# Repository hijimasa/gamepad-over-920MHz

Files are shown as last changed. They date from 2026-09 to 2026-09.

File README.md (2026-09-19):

# gamepad-over-920MHz

**USB ゲームパッドを 920MHz 帯（IM920sL）で無線化する**ファームウェアです。
Bluetooth より遠くまで届く無線リンクに載せ替えつつ、PC からは**普通のゲームパッドのまま**に見せます。
ロボットの遠隔操縦を想定しています。

```
[USBゲームパッド] ─USB(PIO-USB)→ [送信機 XIAO RP2040] ─UART→ [IM920sL]
                                                                 │ 920MHz
[PC] ←USB HID + CDC─ [受信機 XIAO RP2040] ←UART─ [IM920sL] ←─────┘
```

## 特徴

- **軸番号・ボタン番号が元のパッドと一致する。** 送信機がパッドの HID レポート
  ディスクリプタを解析して軸構成を無線で送り、受信機がそれに合わせて HID
  ディスクリプタを実行時に組み立てます。**受信機側の設定は不要**で、
  `/dev/input/js0` の番号が直挿しと同じになるので、既存のソフトをそのまま使えます。
- **フェイルセーフ。** 有効なパケットが 300ms 途絶えると、受信機は全軸中立・
  全ボタン OFF を出力します（実測で約 300ms、ログにも残ります）。
- **リンクの生死が送信機側でも分かる。** 受信機から 2 秒ごとにハートビートを返し、
  「受信機が前方向を受信できているか」まで含めて LED に反映します。
- **チャンネル自動選定。** 起動時に 31〜45 の雑音を測って空いているチャンネルへ移動します。
  複数ペアを同時に運用しても電波を取り合いません。通信が途絶えたら待ち合わせ用の
  ch31 へ自動で戻ります。
- **暗号化（AES-GCM 256bit）。** 同じグループ番号さえ合えば誰でも操作できてしまう
  状態を防げます。
- **USB CDC コンソール。** 設定・ペアリング・電波品質の確認・配線の切り分けができます。

Linux と Windows の両方で動作を確認しています（macOS は未確認ですが、標準の HID と
CDC しか使っていないため動く見込みです）。

## 必要なもの

| | 品目 | 備考 |
|---|---|---|
| 送信機 | Seeed XIAO RP2040 ×1 | CPU 240MHz で動かす（PIO-USB の要件） |
| 送信機 | IM920sL ＋ IM920sL-ADP ×1 | 変換アダプタ経由で 2.54mm に |
| 送信機 | USB Type-A メスコネクタ | ゲームパッド接続用 |
| 送信機 | モバイルバッテリー | 実測の消費電流は約 60mA |
| 受信機 | Seeed XIAO RP2040 ×1 | PC に USB-C で接続 |
| 受信機 | IM920sL ＋ IM920sL-ADP ×1 | |

配線は [docs/schematic/gamepad_wireless_schematic.svg](docs/schematic/gamepad_wireless_schematic.svg)（Rev.3）、
部品表は [docs/gamepad_wireless_BOM.xlsx](docs/gamepad_wireless_BOM.xlsx) を参照してください。

基板（送信機・受信機で共通、100×62mm 2層）の KiCad データと発注用ガーバーは
[hardware/](hardware/) にあります。ブレッドボードやユニバーサル基板で組む場合は
[docs/netlist.md](docs/netlist.md) にネットリストとレイアウト制約があります。

> IM920sL 本体と変換アダプタの取扱説明書は、メーカー（インタープラン）の配布物なので
> リポジトリには含めていません。<https://www.interplan.co.jp/> から入手し、
> `docs/IM920sL_manual.pdf` / `docs/IM920sL_ADP_manual.pdf` として置くと、
> 本 README 中の参照（コマンド仕様・端子表・チャンネル表）と対応します。

## 最短の始め方

```bash
# 1. ビルド環境（arduino-cli）
arduino-cli config add board_manager.additional_urls \
  https://github.com/earlephilhower/arduino-pico/releases/download/global/package_rp2040_index.json
arduino-cli core update-index
arduino-cli core install rp2040:rp2040
arduino-cli lib install "Pico PIO USB" "Adafruit NeoPixel"

# 2. 書込み
./build.sh rx upload /dev/ttyACM0   # 受信機
./build.sh tx upload /dev/ttyACM1   # 送信機

# 3. ペアリング（初回だけ。両機を 50cm 以内に置く）
#    起動後 5 秒以内（LED が水色の速い点滅）か、赤点滅中に
#    受信機 → 送信機 の順に BOOTSEL を 3 秒以上長押し

# 4. 確認
tools/jsinfo.py 10     # /dev/input/js0 の軸数・ボタン数とライブの値
```

うまくいくと**両機とも緑点灯**になり、PC に `irlab Wireless Gamepad` として
ゲームパッドが現れます。

詳しい操作は[操作（BOOTSEL ボタン ／ CDC コンソール）](#操作bootsel-ボタン--cdc-コンソール)、
うまくいかないときは[診断に使えるコマンド](#診断に使えるコマンド)を参照してください。

## 免責

**個人が趣味・研究用に作った原理試作です。**動作・性能・安全性のいずれも保証しません。

- 無線の到達距離や通信の安定性は、設置場所の電波環境に大きく左右されます。
  同じ構成でも結果は異なります。
- ロボットなど**物理的に動くものを制御する用途では、本装置とは独立した非常停止手段を
  必ず用意してください。**受信側に 300ms のフェイルセーフを実装してありますが、
  これは「通信が途絶えたら中立を出力する」だけのもので、機器の安全を保証するものでは
  ありません。
- 本リポジトリの成果物（ファームウェア、回路図、基板データ、資料）を使用した結果
  生じたいかなる損害についても、作者は責任を負いません。
- 920MHz 帯の利用は国と地域の法令に従ってください。IM920sL は日本国内の電波法認証を
  取得済みの製品ですが、**モジュールを改造したり国外で使用したりする場合は、
  使用者の責任において適法性を確認してください。**

不具合や改善点を見つけたら Issue や Pull Request で教えていただけると助かります。

## ライセンス

MIT License（[LICENSE](LICENSE)）。無保証です（上記「免責」および LICENSE の
"AS IS" 条項を参照）。

---

以下は実装と実機検証の詳細です。立ち上げで踏んだ問題（PIO-USB の 240MHz 要件、
TxD/RxD 逆接続の切り分け、コア1 だけが死ぬ故障モードなど）も記録してあります。

## ビルドと書込み

```bash
./build.sh tx                       # 送信機をビルド
./build.sh rx                       # 受信機をビルド
./build.sh tx upload /dev/ttyACM0   # ビルドして書込み
```

必要な環境:

- arduino-cli ＋ `rp2040:rp2040`（earlephilhower コア）
- ライブラリ `Pico PIO USB`、`Adafruit NeoPixel`
- FQBN
  - TX: `rp2040:rp2040:seeed_xiao_rp2040:usbstack=tinyusb,freq=240`
    （PIO-USB は 12MHz の倍数が必要。**120MHz ではタイミング余裕が足りず列挙に失敗した**ので 240MHz。
    `WG_FREQ=120 ./build.sh tx` で変更可）
  - RX: `rp2040:rp2040:seeed_xiao_rp2040:usbstack=tinyusb`

書込みは 1200bps タッチで自動的にブートローダへ入る。入らないときは BOOTSEL を押しながら
USB を挿し、`RPI-RP2` に `build/<role>/*.uf2` をコピーする。

## 構成

```
firmware/common/     TX・RX 共通（arduino-cli には --library で渡す）
  packet.h           無線パケット（State 12 バイト / Info 10 バイト）
  im920sl_config.h   IM920sL の設定・送受信（元からあったもの＋追記）
  im920_diag.h       配線切り分け用の diag / raw / scan
  hid_gamepad_map.h  パッドの HID ディスクリプタを解析して状態を取り出す（TX）
  hid_desc_builder.h HID ディスクリプタを実行時に組み立てる（RX）
  status_led.h       オンボード LED の状態表示
firmware/tx/tx.ino   送信機
firmware/rx/rx.ino   受信機
tools/console.py     CDC コンソールにコマンドを送る補助ツール
```

## 状態表示 LED

XIAO RP2040 のオンボード NeoPixel（GPIO12／電源 GPIO11）と三色 LED（R17/G16/B25）を同時に駆動する。

| 色 | 状態 |
|---|---|
| 赤の点滅 | 接続なし（TX: パッド未接続か送信が通らない／RX: フェイルセーフ中） |
| 黄の点滅 | ペアリング中 |
| 緑の点灯 | 接続中（送信機は**受信機からの応答が届いている**ときだけ） |
| 青の点灯 | 設定ブリッジ中 |
| 白の点滅 | 起動処理中 |
| **水色の速い点滅** | **BOOTSEL ボタン受付中（起動直後 5 秒）** |
| 赤紫の速い点滅 | IM920sL の設定に失敗 |

## 操作（BOOTSEL ボタン ／ CDC コンソール）

SW1 は未実装なので **BOOTSEL ボタン**を使う。電源投入時に押したままだと書込みモードに
入ってしまうため、**電源を入れてから押す**必要がある。押せるタイミングは 2 つ:

**1. 起動直後の受付ウィンドウ（LED が水色の速い点滅、5 秒間）**

電源を入れると 白点滅（起動処理）→ **水色の速い点滅（受付中）** と変わる。
水色の間に押す。

**2. 運用中、リンクが確立していないとき（LED が赤点滅）**

組み立て直後でまだペアリングしていない状態は赤点滅になるので、**そのまま押せばよい**。
緑点灯（正常動作中）のときはボタンを一切読まないので、運用中の通信を乱すことはない。

- 短押し（3 秒未満）→ 設定ブリッジ
- **3 秒以上の長押し → ペアリング**（TX＝子機、RX＝親機。両機を 50cm 以内に置く）

押している間は LED が黄点滅になるので、3 秒の長押しはそれを見ながら数えられる。

> BOOTSEL の読み取りは XIP（フラッシュ実行）を一瞬止めてもう一方のコアを idle にするため、
> PIO-USB が動作中は避けたい。そのため送信機では、パッドが列挙済みになるか起動から
> 15 秒経つまでは運用中のポーリングを行わない。

### 組み立て後の初回手順

1. 受信機を PC に、送信機にゲームパッドとモバイルバッテリーを繋ぐ
2. 両方とも赤点滅になる（＝まだペアリングしていない）
3. 両機を 50cm 以内に置く
4. **受信機の BOOTSEL を 3 秒以上長押し**（親機として登録パケットを送る）
5. すぐに**送信機の BOOTSEL も 3 秒以上長押し**（子機として受け取る）
6. 成功すると両方とも緑点灯になる

ペアリングは Flash に保存されるので**初回だけ**でよい（[ペアリングは初回だけ](#ペアリングは初回だけ) 参照）。

USB-C の CDC コンソール（`tools/console.py` か `screen /dev/ttyACM0 115200`）:

| コマンド | 内容 |
|---|---|
| `help` | コマンド一覧 |
| `status` | IM920sL の設定値、受信状況（RSSI・seq 欠番）、パッドの状態 |
| `config` | AutoConfig（目標値と違う項目だけ ENWR で書込み） |
| `pair` | ペアリング |
| `bridge` | USB CDC ↔ IM920sL の透過ブリッジ |
| `dump` | （TX）HID 生レポートの表示 |
| `map` | （TX）解析した HID マップ |
| `profile` / `reset` | （RX）HID 構成の表示／既定値に戻して再起動 |
| `diag` / `raw <cmd>` / `scan` | IM920sL の配線・応答の切り分け |

## ペアリングは初回だけ

グループ番号は `ENWR` でモジュールの Flash に書かれる不揮発設定なので、電源を切っても残る。
実測（両機を再起動して確認）:

```
再起動前: TX RDGN=0001D9D8 / RX RDGN=0001D9D8
再起動後: TX RDGN=0001D9D8 / RX RDGN=0001D9D8   ← 保持
link: UP  RSSI=-19dBm  packets=116 bad=0        ← 自動で復帰
```

ペアリングが要るのは **初回**と、**どちらかのモジュールを交換したとき**
（グループ番号は親機の固有 ID から決まる）、あるいは `RDGN` が `FFFFFFFF` に
戻ってしまったときだけ。**ファームを書き直しても不要**（`im920AutoConfig()` は
STNN/STRT/STCH/STPO/STTR しか触らない）。

⚠ Flash の書換えは全項目合計で 10 万回まで。ペアリングを不必要に繰り返さないこと。
`im920AutoConfig()` も「目標値と違う項目だけ」書くので、設定が合っていれば書き込まない。

## 軸番号・ボタン番号を元のパッドに合わせる仕組み

既存の操縦ソフトが `/dev/input/js0` を直接読んでいる場合、軸とボタンの並びが
元のパッドと一致していないと、受信機に差し替えた途端に割り当てがずれる。
joydev は **ABS\_\* コードの昇順**に軸番号を振る
（X=0, Y=1, Z=2, Rx=3, Ry=4, Rz=5, Hat=6,7）ので、**元のパッドに在る軸の集合**が
一致していれば番号も一致する。そのため、

1. TX は VID:PID の決め打ち表ではなく、**HID レポートディスクリプタを解析**して
   Usage（X, Y, Z, Rx, Ry, Rz, Hat switch, Button 1..n）の位置を求める。
   → どのパッドでも Linux の hid-generic と同じ割り当てになる。
2. TX は軸の種類（axisMask）とボタン数を **Info パケット**で 2 秒ごとに送る。
3. RX は受け取った構成を EEPROM に保存し、**HID ディスクリプタを実行時に組み立てる**。
   構成が変わったときは保存して自動で再起動し、新しいディスクリプタで列挙し直す。

つまり **受信機側の設定は不要**。送信機にパッドを繋げば、受信機が自動的に同じ形の
ゲームパッドとして PC に見えるようになる（初回は 1 回だけ自動再起動する）。

`dump` で生レポート、`map` で解析結果、RX の `profile` で現在の構成を確認できる。

## Linux 以外の OS で使えるか

受信機は標準的な **USB HID ゲームパッド＋CDC の複合デバイス**なので、Windows / macOS でも
追加ドライバなしで動く。実際のディスクリプタ:

```
bDeviceClass 239 / bDeviceSubClass 2 / bDeviceProtocol 1   ← IAD 複合デバイス宣言
  インタフェース 0,1: CDC（Communications + CDC Data）
  インタフェース 2  : HID（Usage Page = Generic Desktop, Usage = Game Pad）
```

- **HID**: Windows 標準の HID ドライバで動く。`joy.cpl`・DirectInput・RawInput から見える。macOS も標準対応
- **CDC**: Windows 10/11 は `usbser.inf` 内蔵で COM ポートとして見える。macOS は `/dev/cu.usbmodem*`
- **IAD 宣言**がないと Windows が複合デバイスを正しく分解できないが、TinyUSB が付けている

### 注意点

- **XInput ではない**。Windows で XInput 専用のゲームからは見えない。
  これは F310 を D モードで使うのと同じ制約。
  DirectInput / RawInput 対応のソフトなら問題ない。
- 軸・ボタン番号は、Linux の joydev が ABS コード順、Windows の DirectInput が
  HID Usage 順で決まるので、同じ Usage を出している限り一致するはず。**Windows 実機は未確認**。
- VID:PID は Adafruit の既定値 `239a:cafe` のまま。機能上は問題ないが、
  外部に配布するなら自前の PID を用意するのが望ましい。

### Windows 向けに入れてある対策

1. **シリアル番号の衝突回避** — 手元の 2 枚は同じチップ ID（`4250305539333104`）を返す。
   Windows は VID/PID/シリアルでインスタンスを識別するため、同じ PC に両方挿すと衝突しうる。
   役割の接頭辞を付けている（`WGTX-...` / `WGRX-...`）。
2. **HID ディスクリプタのキャッシュ対策** — Windows はレポートディスクリプタを
   VID/PID/**REV** 単位でキャッシュする。受信機はプロファイル学習でディスクリプタを
   作り直すので、構成から `bcdDevice` を生成して別リビジョンとして見せている
   （例: axisMask 0x27・ボタン 12・ハットあり → `bcdDevice = 27.19`）。

## 取扱説明書との照合（docs/IM920sL_manual.pdf Rev.1.5）

公式資料と全コマンド・全設定値を突き合わせ済み。**仕様違反は無かった。**

- **ch31＋高速モード（STRT 1）は仕様上有効**。`STCH` は「01〜29、31〜45」とだけ規定され、
  通信モードによる制限は無い（モードが決めるのは既定値のみ）。
  4s モード（31〜45）は「1 時間あたりの送信時間の総和 **制限なし**」と明記。
  電波法上の処理はモジュール内部で自動なので、ファーム側で duty を管理する義務は無い。
- 発行している 14 コマンドの名称・引数書式・応答・前提条件・順序依存はすべて資料どおり
  （`STNN 0001` に ENWR 必須、`STRT`→`STCH` の順、ペアリング後は RESET 端子必須）。
- 受信行 `aa,bbbb,dd:`、**RSSI は符号付き**（`9Ch`=−100dBm）、TXDA は 1〜32 バイト、
  送信時間 `4.56ms + 80µs × バイト数`（12 バイトで 5.52ms）— すべて一致。
- 触っている設定は次の 5 つだけ（それ以外は初期値のまま）。

  | コマンド | 内容 | 設定値 |
  |---|---|---|
  | `STNN` | ノード番号 | 受信機（親機）= **0001**、送信機 = **0002** |
  | `STRT` | 通信モード | **1**（高速 100kbps） |
  | `STCH` | チャネル | **31**（起動後に空きチャネルへ移動） |
  | `STPO` | 送信出力 | **2**（10mW） |
  | `STTR` | キャリアセンス NG 時の自動リトライ | **00**（再送はファーム側で判断する） |

- **ADP の J1/J2 対応**も回路図で確認。`J1-n = 本体 pin(2n−1)`、`J2-n = pin(2n)`。
  本体 pin1 は資料により `IO1/BUSY`、ADP 回路図では `IO1/RTS` と表記が違うが同じ端子。

### ユニキャストと ACK について

`TXDU`（ユニキャスト）は実在し「**OK は相手に届いたことを示す**」と明記されている。
ただし**ルート探索を行い、失敗時は自動で最大 10 回リトライ**するため遅延が大きくばらつく
（資料も「リアルタイム性が要求される用途では十分ご注意ください」と注意喚起）。
30ms 周期の操縦データには不向きなので採用していない。

各パケットは差分ではなく**現在の全状態**を持つので、落ちても次のパケットが完全に
上書きする。再送は「古い状態を届けたうえに新しい状態を遅らせる」ため逆効果。
取りこぼしへの対処は受信側の 300ms フェイルセーフで行う。

なお `TXSB`（センドバック送信）はルート探索なしで送信元へ返せるので、
ハートビートをブロードキャストからユニキャストに変えたい場合の選択肢になる（未採用）。

### 4s モードの送信休止規定（2026-09-19 に再確認）

取扱説明書 表1・§7-3 より、ch31〜45（4s モード）の規定は次のとおり。

| 項目 | 4s モード（ch31〜45） | 360s モード（ch01〜29） |
|---|---|---|
| キャリアセンス時間 | 約 6ms | 128µs〜1ms |
| 送信休止時間 | **52ms 以上** | 2ms 以上 |
| 1 時間あたりの送信時間の総和 | **なし** | 360 秒以内 |
| 送信時間制限 | 3.9 秒以下 | 400ms 以下 |

「1 時間 360 秒」の総和制限は ch01〜29 だけの話で、本プロジェクトの ch31〜45 には無い。

代わりに効くのが**送信休止 52ms** で、挙動は「最初の送信から 3.9 秒を超えたら 52ms 休止」
「4 秒経過前に 52ms 以上空けば窓がリセットされる」。
1 回の占有はキャリアセンス約 6ms ＋ 送信 6ms（12 バイト時 5.52ms を切り上げ）＝ 約 12ms
なので、計算上は **64ms 間隔**あれば窓がリセットされ続けるはず。

**ただし実測はこの計算と合わない。** ブリッジ経由でファームを介さず TXDA を打った結果:

| 送信間隔 | 55ms | 65ms | 75ms | 90ms | 120ms | 150ms |
|---|---|---|---|---|---|---|
| NG 率 | 20.0% | 17.5% | 12.5% | 8.0% | 4.0% | **0%** |

64ms を超えても NG は残り、0 になるのは 150ms 以上。**機構は特定できていない。**

なお **NG は一度も連続しなかった**（90ms で 12 回、120ms で 6 回、すべて単発）。
欠落は最悪 2 周期分なので、受信側フェイルセーフ 300ms には届かない。

⚠ 暗号化を有効にすると 1 パケットが **24 バイト増える**（§7-4）ので、
12 バイトのパケットは 36 バイト相当（7.44ms）になる。上の測定は暗号化なしの値。

## UART の高速化（115200bps）

12 バイト送信の UART 時間は 19200bps で約 16ms あり、**電波の送信時間 5.5ms の 3 倍**を
食っていた。`SBRT 7` で 115200bps にすると約 2.7ms になる。

`SBRT` は資料に「Flash メモリに記憶します」の記載が無く揮発性とみられるため、
**毎起動で設定しても Flash 書換え回数を消費しない**。起動時に `im920SetupBaud()` が
`RDVR` の応答でモジュールの現在のボーレートを判別し、必要なら 115200 に上げる。
判別に失敗したときは元のボーレートのまま動作を続ける。

## パケット暗号化＋送信元認証

AES-GCM 256bit。**同じグループ番号さえ合えば誰でもロボットを操作できる**状態を防ぐ。

```
enc <16進64桁>   キーを設定して有効化（両機に同じキーを入れること）
enc off          無効化（キーは残る）
```

- `STKY` は ENWR 中のみ実行可能で Flash に記憶される（読出しコマンドは無い）ため、
  明示的なコマンドのときだけ設定する
- 通信時間が 24 バイト分（高速モードで約 1.9ms）増える
- ペアリング（STGN）時は常に非暗号化パケットなので、順序はどちらでもよい
- 実測: 暗号化オンで `ng=0%`、`bad=0`、`lostEvents=0`

## 無線パケット

**State（12 バイト。30〜100ms ごと）**

| オフセット | 内容 |
|---|---|
| 0 | seq |
| 1–2 | buttons（u16 LE、bit0 = ボタン 1） |
| 3 | hat（0〜7 が方向（0=上、時計回り）、8 = 中立） |
| 4–9 | 軸 6 個 = **X, Y, Z, Rx, Ry, Rz**（0x80 が中立。スティック/トリガではなく **HID Usage 順**で並べている。理由は「軸番号・ボタン番号を元のパッドに合わせる仕組み」を参照） |
| 10 | flags（bit0: パッド接続中） |
| 11 | checksum（byte0〜10 の XOR） |

**Heartbeat（4 バイト。受信機 → 送信機、2 秒ごと）**
`0xC3`, seq, 受信機側の RSSI(i8), XOR。

`TXDA` はブロードキャストで ACK がないため、送信機は自分の電波が届いたかを知る手段がない。
そのままだと送信機の緑は「モジュールが送信を受理した」ことしか意味せず、
**受信機の電源が落ちていても緑**になってしまう。そこで受信機から定期的に投げ返し、
送信機はこれが 1.5 秒途切れたら赤点滅にする。受信機側の RSSI も載せているので、
送信機のコンソールで**両方向の電波強度**が見える（距離試験に便利）。

⚠ **周期を短くすると前方向のパケットが落ちる。** 半二重なので、受信機が
ハートビートを送っている間はパッドのパケットを受け取れない。実測:

| ハートビート周期 | 受信パケット | seqDrop | 300ms 途絶の回数 |
|---|---|---|---|
| 500ms | 11502 | 901（7.8%） | 870 |
| 2000ms | 203 | 0（0%） | 0 |

送信機の NG 率（キャリアセンス）は 2Hz でも +1% 程度しか増えないので、
一見すると安く見えるが、**効いてくるのは受信側の取りこぼし**のほう。
既定は 2 秒、送信機のリンク判定タイムアウトは 5 秒。
受信機は応答を待たずに投げる（`im920SendNoWait`）ので HID の処理は止まらない。

**Info（10 バイト。2 秒ごと）** `0xA5`, version, axisMask, buttonCount, caps(bit0=hat), VID, PID, XOR。
長さでどちらのパケットか判別する。

送信は「状態が変わったら即送信＋無変化でも 100ms ごと」「最短間隔 30ms」。`TXDA` が NG でも
再送はせず次の周期に任せる。

## 動作中に突然リンク断になる問題（2026-09-19 修正）

送信機のモジュールは**半二重**で、自分が送信している間は受信できない。
そのため送信間隔によって、受信機からのハートビートの取りこぼし率が大きく変わる。

| 送信間隔 | ハートビート欠落 |
|---|---|
| 60ms（パッド静止） | 6.6% |
| **30ms（操作中）** | **29.5%** |

ハートビートは 2 秒周期なので、旧設定の `HB_TIMEOUT_MS = 5000` では
**2 回連続で落ちるだけ**（操作中は 8.7%／2 秒ごと）でリンク断と誤判定していた。
平均 20〜30 秒に 1 回、動作中に突然赤点滅する原因。

さらに `CH_REVERT_MS = 12000` も同じハートビート頼りで、6 回連続の欠落で
ch31 に戻って再走査に入る。受信機が取り残されるので**本当の通信断**になっていた。

| 定数 | 変更前 | 変更後 | 必要な連続欠落 |
|---|---|---|---|
| `HB_TIMEOUT_MS` | 5000 | **15000** | 2 回 → 7 回 |
| `CH_REVERT_MS` | 12000 | **30000** | 6 回 → 15 回 |

ロボットの保護は受信側の 300ms フェイルセーフが行うので、送信側のリンク判定を
鈍くしても安全性は落ちない（送信機の LED は状態表示にすぎない）。

修正後、操作中相当（30ms 連続送信）で 225 秒間、`link: DOWN`・再走査とも 0 回。
またハートビートの欠落自体も 29.5% → 約 7% に下がった。誤判定による再走査が
さらにハートビートを失わせる悪循環になっていたとみられる。

**半二重による取りこぼし自体は解消していない。** しきい値を実測に合わせた修正である。

## `pad: reports` が増えないのは異常ではない

送信機の `status` が出す `reports` は、**パッドから HID レポートが届いた回数**。
多くのゲームパッド（Logitech F310 など）は状態が変化したときだけレポートを返すので、
**パッドを触っていなければ `reports=1` のまま**になる。これは正常。

実際に操作すると増える（実測で 2512 まで上がることを確認済み）。
PIO-USB が死んでいるかどうかは `usb` コマンドの
`epErr` / `epStall` / `コア1: loop1 通算` で判断すること。

## 動作中の突然の再起動＝core1（PIO-USB）の停止

送信機に**再起動しても消えないブラックボックス記録**（`__uninitialized_ram`）を入れて
現行犯で捕らえた結果、原因が確定した。

```
ブラックボックス: ソフト再起動 1 回 / 赤点滅 1 回
  赤点滅の内訳: パッド切断=1 USBホスト停止=0 ハートビート途絶=0 受信機側=0
  直近の自動再起動: コア1(PIO-USB)の停止
                    （稼働 265717ms, reports=1 ok=2764 ng=309, ハートビート 223ms 前）
```

- **無線は無関係。** 停止時点でハートビートは 223ms 前に届いており、リンクは健全だった
- 赤点滅の原因は**パッド切断**で、その 9 秒後に監視機構が再起動をかけている
- `loop1()` は `g_hostTicks++` が先頭なので、止まっているのは **`USBHost.task()` の中**

受信機側のログで実際の通信断も測れた:

```
途絶 6 回 / 継続時間: [0, 1, 10, 14, 2988, 20930] ms
```

**20.9 秒**の内訳は「core1 停止の検出待ち 10 秒 ＋ 再起動 ＋ チャンネル再走査」。
再起動後は ch31 から始まるため、受信機が待ち合わせに戻るまで待つことになっていた。

### 対策（根本原因ではなく復帰時間）

`USBHost.task()` が固まる原因はライブラリ内部で手が出ないため、**復帰を速くする**方針。

| 項目 | 変更前 | 変更後 |
|---|---|---|
| `HOST_REBOOT_MS`（停止と判断するまで） | 10000 | **3000** |
| 再起動後のチャンネル | ch31 から再会合 | **停止直前の ch へ直接復帰**（再走査なし） |

core1 は常時回っているので 3 秒止まれば確実に死んでいる。
またチャンネルをブラックボックスに保存しておけば、受信機はそこに残っているので
再会合が不要になる。合わせて通信断は 21 秒 → 数秒に縮む見込み。

**根本原因（`USBHost.task()` が固まる理由）は未解明のまま。**

### ネイティブ USB ホストへの移行を検討し、断念した（2026-09-19）

PIO-USB をやめて RP2040 の**ネイティブ USB コントローラ**をホストにすれば、
core1 も PIO も USB に関与しなくなり、この停止は構造的に消える。
XIAO の USB-C に OTG 変換でパッドを繋ぎ、給電は J1 から入れる構成。

- arduino-pico は `usbstack=tinyusb_host`（Adafruit TinyUSB Host (native)）に対応
- 5V ピンから USB-C の VBUS へ逆流することは実機で確認済み（J1 給電で動作した）

最小構成（[firmware/hosttest/](firmware/hosttest/)）で検証した結果:

| 段階 | 結果 |
|---|---|
| `USBHost.begin(0)` | ✅ 通る |
| USB 機器の検出（`tuh_mount_cb`） | ✅ 呼ばれる |
| HID として列挙（`tuh_hid_mount_cb`） | ✅ 呼ばれる。VID:PID も取得できる |
| `tuh_hid_receive_report()` | ✅ 成功を返す |
| **レポートの受信** | ❌ **一度も届かない** |

`rearm=0 rep=0` が延々と続く（`rearm=0` は「転送が保留中」を意味し正常）。
つまり**転送は armed のまま完了しない**。ゲームパッドでもマウスでも同じ。
同じ TinyUSB の HID クラスドライバで PIO-USB 版では動くので、
差分はネイティブ HCD の割り込み IN 転送にある。

`hcd_rp2040.c` を読んだ限り実装は構造的に正しく見え（割り込みエンドポイントは
15 個のプールから確保、`bInterval` 設定済み、SOF も有効化）、
設定漏れのような分かりやすい原因は見当たらなかった。

**これ以上はライブラリ内部のデバッグになるため打ち切った。**
検証用スケッチは最小再現コードとして残してある。

### NeoPixel との干渉を疑って調べたこと

`Adafruit_NeoPixel::show()` は RP2040 で PIO を使う経路でも、実行中ずっと
`noInterrupts()` で割り込みを止める（Adafruit_NeoPixel.cpp:459 と :3336）。
ただし arduino-pico の `noInterrupts()` は `get_core_num()` でコア別に管理されており
（wiring_private.cpp:81）、**core0 で止めても core1 の割り込みは止まらない**。
`show()` は core0、PIO-USB は core1 なので、割り込み阻害が直接の原因という線は薄い。

とはいえ NeoPixel と PIO-USB は **PIO ハードウェアを共有**しており
（そのため `enableNeoPixel()` は `USBHost.begin()` の後に呼ぶ必要がある）、
静的解析だけでは否定しきれない。切り分けのため `neo on|off` コマンドを用意した。
`off` にすると NeoPixel の PIO を確保せず、三色 LED（R=17/G=16/B=25）だけで
状態表示する。設定は EEPROM に保存され、再起動しても残る。

**まだ結論は出ていない。** core1 停止は数分〜数十分に 1 回の頻度なので、
`neo off` で長時間動かして `ブラックボックス` の再起動回数を比較する必要がある。

## 未解明：送信後に消える約 15% のパケット

`TXDA` が OK を返したのに受信機に届かないパケットが約 15% ある。
**実害は確認できていない**が、原因も特定できていないので記録しておく。

切り分けで否定できたもの:

| 疑い | 検証方法 | 結果 |
|---|---|---|
| 電波干渉 | ch31〜45 の RSSI を実測 | −105〜−110dBm。キャリアセンス閾値 −80dBm 超過は 0 |
| 受信機の取りこぼし | `Serial1.overflow()`、行の解析結果を計測 | FIFO 溢れ 0、解釈不能 0、他ノード 0 |
| 受信機の処理落ち | `loop()` の最大間隔を計測 | 最大 22ms（FIFO 溢れの閾値未満） |
| パケット破損 | チェックサム失敗を計測 | `bad=0` |
| ハートビートとの衝突 | `hb off` で比較 | 18.7% / 21.1%。ほぼ差なし |
| 至近距離による受信機の飽和 | 送信出力 10mW / 1mW で比較 | RSSI −12dBm で 21.1%、−21dBm で 22.9%。変わらず |
| 送信間隔 | 60ms / 90ms で比較 | 14.6% / 19.8%。改善せず |

**欠落は必ず単発**（1 個が大半、2 個が数回、3 個以上は 0）。
最悪の空きは約 90〜180ms で、受信側フェイルセーフ 300ms には届かない。
実効更新レートが 2 割ほど落ちるだけで、操作が途切れる現象には繋がっていない。

モジュール内部で CRC を通らなかったパケットが黙って捨てられている可能性が高いが、
モジュールから受信エラー数を読む手段が無いため確認できていない。

## フェイルセーフ

- 有効なパケットが **300ms** 届かない、または flags.bit0 = 0 のとき、RX は全ボタン OFF・
  軸中立・ハット中立の HID レポートを出す。
- 途絶の開始と復帰を CDC にログ出力し、LED を赤点滅にする。
- TX 側もパッドが外れたら中立＋flags.bit0 = 0 を送る。

## 実機の状況（2026-09-18 時点）— **通しで動作**

送信機・受信機とも動作し、パッド → 920MHz → PC の経路が通った。

```
送信機 TX: pad connected  VID:PID=046D:C216 axisMask=0x27 buttons=12 hat=1
           tx: ok=143 ng=0 (0%)   送信間隔 30ms
受信機 RX: link UP  RSSI=-12〜-33dBm  packets=1334 bad=0
           profile: axisMask=0x27 (X Y Z Rz) buttons=12 hat=1  src=046D:C216
PC:        /dev/input/js0 "irlab Wireless Gamepad"  軸 6 個 / ボタン 12 個
```

軸・ボタンの数が元の F310（D モード）と一致している。受信機は送信機から届いた
Info パケットでパッド構成を自動学習し、EEPROM に保存して HID ディスクリプタを
作り直した（ログ: `パッド構成が変わりました: axisMask 0x3F->0x27 buttons 16->12`）。

### 立ち上げでつまずいた点（記録）

**1. IM920sL が無応答 → TxD/RxD の逆接続（両基板とも）**

`swap` コマンド（ソフト UART で GPIO1 送信／GPIO0 受信）で確定した:

```
TxD/RxD 逆接続テスト（GPIO1 から送信し、GPIO0 で受信する）
  リセット後の受信: 19 バイト  "IM920sL Ver.01.12"
  RDVR の応答:      19 バイト  "IM920sL Ver.01.12"
```

D6/D7 を入れ替えて解決。1 枚目はさらに芋半田の手直しも必要だった。
判別の決め手は **BUSY ピン**で、生きているモジュールは BUSY を L に駆動し、
リセットで変化する（死んでいる側は H に固着したままだった）。

**2. USB ゲームパッドが列挙されない → CPU クロックと XInput**

- PIO-USB はビットバンギングのため **120MHz ではタイミング余裕が足りなかった**。
  アドレス 0 での通信と SET_ADDRESS までは成功し、アドレス 1 の転送が全滅する、
  という症状。**240MHz にして解決**（build.sh の既定値）。
- 繋いでいた F310 が **XInput モード**（046D:C21D, class 255/subclass 0x5D）で、
  HID ではないため HID ドライバが掴めなかった。背面スイッチを **D** にして解決。

**3. Adafruit_NeoPixel が PIO を使う**

RP2040 版の NeoPixel は `pio_claim_free_sm_and_add_program` で PIO を掴む。
PIO-USB は TX プログラムを PIO0 のオフセット 0 に置く必要があるため、
送信機では起動直後は三色 LED だけで表示し、`USBHost.begin()` の後に
`enableNeoPixel()` を呼ぶ順序にしてある。

### 確認できた設計上の疑問

- **高速モード（STRT 1）＋ ch31 は受け付けられた**（`RDCH=31` が読める）。
  時間総和の制限がない 4s モードが使えるので、送信頻度を落とす必要はない。
- ペアリング（STGN → RESET 端子で再起動）は成功し、親機・子機の `RDGN` が
  `0001D9D8` で一致した。子機は `GRNOREGD` を出力した。
- NG 率（干渉のない状態、`rate N` / `hb N` コマンドで測定）:

  | 条件 | NG 率 |
  |---|---|
  | 送信間隔 30ms・ハートビートなし | 1% |
  | 送信間隔 30ms・ハートビート 2Hz（既定） | 2% |
  | 送信間隔 30ms・ハートビート 4Hz | 3% |
  | 送信間隔 20ms（50Hz） | 1% |

  内訳はすべて「モジュールが NG」＝キャリアセンス失敗で、BUSY 待ちや無応答は 0。

### 外部干渉とチャンネル自動選定

測定中、ch31 の NG 率が一時的に 26〜41% まで悪化した。**送信間隔を 30→60→100ms と
広げても NG 率が変わらなかった**（26%→30%→34%）ことから、自分の送信が原因ではなく
外部の電波でチャンネルが塞がれていると判断できる。干渉は時間とともに移動し、
別の時点では ch35 が 63% に悪化した。**固定のチャンネル割り当てでは追随できない。**

そこで **ch31 を待ち合わせ専用**にして、送信機が起動時に空きチャンネルを選ぶ方式にした。

```
1. 起動時は両機とも ch31（AutoConfig が Flash の既定値に戻すので必ずここに来る）
2. ch31 でリンク確立（送信機は受信機のハートビートを待つ）
3. 送信機が 31〜45 を STCH で切り替えながら RDRS で雑音を測り、最も静かな ch を選ぶ
4. チャンネル変更通知（3 バイト）を 6 回送ってから、自分も移動
5. 受信機は通知を受けて移動
6. 双方とも「12 秒間 相手から受信が無ければ ch31 へ戻る」（片方だけ移動した場合の復帰）
```

**Flash を消費しない**のが利点。`STCH` は取扱説明書に「ENWR コマンド実行時は Flash
メモリに記憶します」の記載が無く揮発的なので、ENWR なしで発行すれば書換え回数
（全項目合計 10 万回）を使わない。EEPROM も使わない（送信機では `EEPROM.commit()` が
`rp2040.idleOtherCore()` を使うため、PIO-USB 稼働中の書込みはデッドロックの危険がある）。

実測:

```
起動 → 走査 → ch42 を選択・移動   tx ng=8%, bad=0, lostEvents=0

［復帰試験］受信機だけ ch38 に強制
  → リンク断（受信機は中立を出力）
  → 約12秒で両機とも ch31 へ復帰
  → 送信機が再走査して ch40 を選択・通知 → 両機 ch40 で確立、以降安定
```

### 複数ペアを同時に運用するとき

グループ番号で**論理的には分離される**（取扱説明書「グループ番号が一致するモジュールのみ
通信」）ので、他のペアのデータが混ざることはない。ただし同じチャンネルでは**電波を取り合う**
（キャリアセンスは「その通信チャンネルの RSSI 値が **-80dBm 以上**のときは NG」）。
手元で -21dBm なので、同じ部屋の別ペアは確実にこの閾値を超える。

上記の自動選定により、ペアごとに別チャンネルへ分かれる。

⚠ 複数ペアが同時に起動すると一時的に全機が ch31 に集まる。走査と移動は数秒で終わるが、
起動タイミングをずらせるならずらしたほうが確実。

`ch N`（31〜45）で手動指定もできる。送信機で実行すると受信機にも通知が飛ぶ。
どちらも揮発的なので、再起動すると ch31 に戻って改めて走査する。

`ttr N` でキャリアセンス NG 時の自動リトライ回数も変えられる（既定 00＝リトライなし）。
遅延と引き換えに NG を減らせるので、干渉が避けられない環境では選択肢になる。

### 診断に使えるコマンド

```bash
tools/console.py -p /dev/ttyACM0 -m 12 diag   # IM920sL の配線切り分け
tools/console.py -p /dev/ttyACM0 -m 12 swap   # TxD/RxD 逆接続の判定（決め手）
tools/console.py -p /dev/ttyACM0 -m 20 rscan  # リセットしながらボーレート総当たり
tools/console.py -p /dev/ttyACM0 -m 5 usb     # USB ホストの状態・線の静電容量
tools/console.py -p /dev/ttyACM0 "rate 20"    # 送信間隔を変えて NG 率を測る
tools/console.py -p /dev/ttyACM0 "ch 35"     # チャネル変更（測定用。再起動で戻る）
tools/console.py -p /dev/ttyACM0 "ttr 03"    # キャリアセンス NG 時のリトライ回数
tools/console.py -p /dev/ttyACM1 "hb 1000"   # ハートビート周期（off で停止）
tools/console.py -p /dev/ttyACM0 "enc <16進64桁>"  # 暗号化キー設定（両機に同じキー）
tools/jsinfo.py 10                            # js0 の軸数・ボタン数とライブの値
```

TinyUSB 本体のログを取りたいときは README 末尾の `wg_dbg.h` の項を参照。

## 残っている実機確認

1. [x] IM920sL が応答する
2. [x] `STRT 1` の後の `STCH 31` が OK になる
3. [x] ペアリングと `RDGN` の一致
4. [x] PIO-USB で元パッドが列挙され、`map` で解析できる
5. [x] 送信頻度ごとの NG 率。**初期の「30ms で 0%」は短時間の測定で、
       長時間動かすと 30ms で約 22%、60ms で約 8% になる**（2026-09-19 再測定）。
       NG は必ず単発で、次の周期で回復するため実害は無い。遅延の実測はこれから
6. [ ] `/dev/input/js0` として認識され、元のパッド向けに書かれたソフトが
       そのまま動くか（js0 としての認識と軸/ボタン数の一致までは確認済み。
       実アプリでの動作確認が残り）
7. [ ] フェイルセーフ（TX 電源断・アンテナ遮蔽）
8. [ ] モバイルバッテリーが低電流で自動 OFF しないか

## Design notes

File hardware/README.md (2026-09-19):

# 基板データ（KiCad）

原理試作用の基板。送信機と受信機は **1 種類の基板**でまかなう
（受信機は USB-A まわりを実装しないだけ。[../docs/netlist.md](../docs/netlist.md) 参照）。

## 構成

```
hardware/
├── make_footprints.py   モジュール用フットプリントの生成
├── make_board.py        基板（配置・配線・ベタ・DRC・作図）の生成
├── make_checksheet.py   寸法確認用 1:1 印刷シートの生成
├── footprints.pretty/   生成されたフットプリント
├── board/               基板データ（.kicad_pcb）と確認用 PDF、DRC レポート
└── check/               確認シート（PDF/SVG）
```

フットプリントは手書きではなくスクリプトで生成している。寸法が判明したら
`make_footprints.py` の定数を直して再生成する。

## ⚠ 実装前に寸法を確認すること

**`check/footprint_check.pdf` を 100%（拡大縮小なし）で印刷し、実物を重ねて確認する。**
シートに 50.0mm の基準線を入れてあるので、まずそれを定規で測って印刷倍率を確かめる。

| 部品 | 寸法 | 根拠 |
|---|---|---|
| IM920sL-ADP | J1–J2 間 **25.4mm**、ピン1 は上端から 5.71mm、ピッチ 2.54mm×10、外形 30.0×40.0mm | 製品資料 Rev.1.0 外形寸法図で確認済み |
| XIAO RP2040 | 2 列の間隔 **15.24mm**（0.6in）、ピッチ 2.54mm×7 | 実測で確認済み |

どちらも実測で確定済みだが、発注前にもう一度確認シートを重ねること。
ここを間違えると基板が使えない。

## 生成と確認

```bash
python3 hardware/make_footprints.py     # フットプリント
python3 hardware/make_board.py          # 基板 + DRC + 確認用 PDF
python3 hardware/make_checksheet.py     # 確認シート
python3 hardware/make_gerber.py         # 発注用ガーバー + ドリル
```

`make_board.py` は実行のたびに `board/` を作り直し、最後に DRC を回して
`board/drc.txt` に結果を書く。**現状 0 violations / 0 unconnected pads。**

KiCad 6 の Python API（`pcbnew`）を使っている。KiCad 7 以降なら `kicad-cli` で
同じことがもっと簡単にできる。

## 基板の概要

| 項目 | 値 |
|---|---|
| 外形 | 100 × 62 mm、2 層 |
| 固定穴 | φ3.2（M3）× 4、四隅（4,4）（96,4）（4,58）（96,58） |
| 配線幅 | 0.4mm（全ネット） |
| クリアランス | 0.2mm（ベタは 0.3mm） |
| ベタ | 両面 GND。左上 22 × 20mm はアンテナ用に銅を抜いてある（シルクに `ANT KEEPOUT`） |

確認用の作図:

| ファイル | 内容 |
|---|---|
| `board/gamepad_over_920MHz-top.pdf` | 表面（F.Cu + シルク） |
| `board/gamepad_over_920MHz-bottom.pdf` | 裏面（B.Cu） |
| `board/gamepad_over_920MHz-layout.pdf` | 両面重ね |
| `board/placement.pdf` | 部品配置のみ |

## 発注データ

`make_gerber.py` が `board/gerber/` に一式を書き出し、
`board/gamepad_over_920MHz-gerber.zip` にまとめる。**この ZIP をそのまま業者に投げる。**

| 拡張子 | 内容 |
|---|---|
| `.gtl` / `.gbl` | 表面 / 裏面 銅箔 |
| `.gto` / `.gbo` | 表面 / 裏面 シルク |
| `.gts` / `.gbs` | 表面 / 裏面 レジスト |
| `.gtp` / `.gbp` | 表面 / 裏面 メタルマスク（手はんだなので未使用） |
| `.gm1` | 外形（100 × 62mm） |
| `-PTH.drl` | スルーホール 50 個（φ0.7 / 0.8 / 0.92 / 1.0 / 2.3） |
| `-NPTH.drl` | 固定穴 φ3.2 × 4 |

発注時の指定:

| 項目 | 値 |
|---|---|
| 層数 | 2 |
| 基板サイズ | 100 × 62 mm |
| 板厚 | 1.6mm |
| 銅箔厚 | 1oz |
| 表面処理 | HASL（有鉛・無鉛どちらでも可） |
| 最小線幅 / クリアランス | 0.4mm / 0.2mm（どの業者の標準仕様でも通る） |

**発注前に業者サイトのガーバービューアで必ずプレビューを確認すること。**
手元にビューアがないため、出力データの目視確認はできていない。

配置は次の条件で決めてある:

- **U2（IM920sL-ADP）は回転 0。** アンテナが J1 のピン1 付近から出るので、
  それが基板左上の空き側（ANT KEEPOUT）に来る。ADP は裏面にコネクタがあるため、
  **ピンソケットで嵩上げして実装する**
- **U1（XIAO RP2040）は 180 度回転。** USB-C が基板下端を向き、
  モバイルバッテリーのケーブルを基板外へ逃がせる
- **J1（USB-A）は変換基板を使わず直付け。** 右端に開口を向ける。
  シェル固定パッドは GND に落としてある

### D+/D− を表裏に分けている理由

XIAO 側は D0(D+) が D1(D−) の**下**、J1 側は D+ が D− の**上**で順序が逆転しており、
1 層では必ず交差する。そのため **D+ は表面、D− は裏面**に分けた。
フルスピード（12Mbps）で配線長 20mm 程度なので実用上は問題ないが、
インピーダンス整合は取っていない。

## 設計方針

レイアウトの制約は [../docs/netlist.md](../docs/netlist.md) にまとめてある。要点だけ再掲:

1. **IM920sL のワイヤーアンテナ周辺はベタ GND・配線・金属を置かない。** 基板端に寄せ、
   できればアンテナを基板外へ出す。飛距離に直結する
2. **USB の D+/D− は短く・等長。** R1/R2（22Ω）は XIAO 側に寄せる。
   PIO-USB はタイミング余裕が少ない（CPU 120MHz では列挙に失敗する）。
   ※ 実際の配線では並走ではなく表裏に分けている（理由は上記）
3. C3（0.1µF）は IM920sL の VCC 直近、C2（10µF）はその外側
4. C1（47µF）は USB-A の VBUS 直近

RF 性能は保証できない。原理試作として作り、実測しながら直す前提。

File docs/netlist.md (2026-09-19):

# ネットリストと基板設計メモ（Rev.3）

EasyEDA などで回路図を起こし、PCB を設計するための資料。
接続は [docs/schematic/gamepad_wireless_schematic.svg](schematic/gamepad_wireless_schematic.svg) と同じ内容を表にしたもの。

## 1 枚の基板で送信機・受信機の両方をまかなえる

受信機は**送信機から USB-A まわり（J1・C1・R1・R2）を省いたもの**で、それ以外は完全に同じ。
1 種類の基板を作り、実装する部品を変えるだけで両方に使える。

| | 送信機 | 受信機 |
|---|---|---|
| U1 XIAO RP2040 | ● | ● |
| U2 IM920sL + ADP | ● | ● |
| C2 10µF / C3 0.1µF | ● | ● |
| J1 USB Type-A / C1 47µF / R1・R2 22Ω | ● | — |

## 部品

| RefDes | 部品 | フットプリント | 備考 |
|---|---|---|---|
| U1 | Seeed XIAO RP2040 | 2.54mm 7×2（幅 17.78mm） | ソケット実装を推奨（書込み・交換のため） |
| U2 | IM920sL + IM920sL-ADP | 2.54mm 10×2（J1/J2、間隔は ADP 外形図に従う） | ADP の外形 30.0 × 40.0mm、取付穴あり |
| J1 | USB Type-A レセプタクル（メス） | 基板直付け・横型（DS1095-WNR0 相当） | 送信機のみ |
| C1 | 電解コンデンサ 47µF 10V | φ5mm / 2.54mm ピッチ | 送信機のみ。J1 の近くに |
| C2 | 積セラ 10µF | 2.54mm ピッチ または 1206 | U2 の VCC 直近 |
| C3 | 積セラ 0.1µF | 2.54mm ピッチ または 0603/0805 | U2 の VCC 直近 |
| R1, R2 | 22Ω 1/4W | 2.54mm ピッチ または 0805 | 送信機のみ。D−/D+ の直列抵抗 |

XIAO RP2040 のピン配置（外形 17.5 × 20.5mm、2.54mm ピッチ 7×2）:

```
左側（上から）: D0/A0(GPIO26) D1/A1(GPIO27) D2/A2(GPIO28) D3/A3(GPIO29)
                D4/SDA(GPIO6) D5/SCL(GPIO7) D6/TX(GPIO0)
右側（上から）: 5V  GND  3V3  D10/MOSI(GPIO3)  D9/MISO(GPIO4)
                D8/SCK(GPIO2)  D7/RX(GPIO1)
```

IM920sL-ADP は `J1-n = 本体 pin(2n−1)`、`J2-n = 本体 pin(2n)`（製品資料 Rev.1.0 回路図で確認済み）。

## ネットリスト

| ネット | 接続先 |
|---|---|
| `+5V` | U1 5V — J1(USB-A) pin1 VBUS — C1 (+) |
| `+3V3` | U1 3V3 — U2 J1-9 (VCC, 本体 pin17) — C2 (+) — C3 |
| `GND` | U1 GND — U2 J2-9 (GND, 本体 pin18) — J1(USB-A) pin4 — C1 (−) — C2 (−) — C3 |
| `USB_DP` | U1 D0/A0 (GPIO26) — R2 — J1(USB-A) pin3 (D+) |
| `USB_DM` | U1 D1/A1 (GPIO27) — R1 — J1(USB-A) pin2 (D−) |
| `IM_BUSY` | U1 D2/A2 (GPIO28) — U2 J1-1 (BUSY, 本体 pin1) |
| `IM_RESET` | U1 D3/A3 (GPIO29) — U2 J1-10 (RESET, 本体 pin19) |
| `IM_RXD` | U1 D6/TX (GPIO0) — U2 J2-3 (RxD, 本体 pin6) |
| `IM_TXD` | U1 D7/RX (GPIO1) — U2 J1-4 (TxD, 本体 pin7) |

**未接続**（オープンのまま）:

- U1: D4(GPIO6), D5(GPIO7), D8(GPIO2), D9(GPIO4), D10(GPIO3)
- U2: J1-8 (STATUS), J2-8 (REG), IO8〜IO10 ほか上記以外すべて
  - **IO8〜IO10 は必ずオープンのままにすること**。電源投入時にオープン／L でないと
    データモードで起動しない
- SW1 と STATUS LED は Rev.3 で廃止（設定/ペアリングは XIAO の BOOTSEL、
  状態表示は XIAO オンボードのカラー LED を使うため）

## レイアウト制約

ここが基板の出来を分ける。ファームでは救えない部分。

### 1. アンテナのキープアウト（最優先）

IM920sL はワイヤーアンテナ。**アンテナの周囲と真下にはベタ GND・配線・金属部品を置かない**。
基板の端に寄せ、できればアンテナ部分を基板の外へ出す。飛距離はこのプロジェクトの目的そのもので、
ここを妥協すると数十 m 単位で損をする。

### 2. USB の差動ペア D+/D−（送信機のみ）

- **できるだけ短く**、2 本を**等長・等間隔**で並走させる。間にベタや他の信号を挟まない
- R1/R2（22Ω）は **XIAO 側に寄せて**置く
- PIO-USB はソフトウェアでビットを叩いており、タイミング余裕が少ない
  （CPU 120MHz では列挙に失敗し、240MHz が必要だった）。配線が悪いと同じように不安定になる
- ビアは避ける。やむを得ない場合は 2 本とも同じ数だけ通す

### 3. 電源

- C3（0.1µF）を U2 の VCC ピン**直近**に、C2（10µF）をその外側に置く
- C1（47µF）は USB-A コネクタの VBUS 直近（ゲームパッド挿抜時の突入電流対策）
- IM920sL は送信時 27mA typ.。3.3V は XIAO のレギュレータから取る
  （資料に「電源ノイズは受信感度の低下や動作不安定の原因」とあるので、
  スイッチング電源から直接取らない）

### 4. その他

- 両面ベタ GND、ビアで縫う。ただしアンテナ下は除く
- XIAO はソケット実装を推奨（BOOTSEL と RESET ボタン、USB-C コネクタに手が届くこと）
- USB-A コネクタは抜き挿しの力がかかるので、固定用のパッドかネジ穴を設ける
- 送信機はモバイルバッテリー駆動。実測の消費電流は約 60mA

## 確認事項

- **IM920sL-ADP の J1/J2 の間隔**は製品資料の外形寸法図（外形 30.0 × 40.0mm、
  J1/J2 は 2.54mm×9 = 22.86mm）を実測で確認してからフットプリントを作ること
- USB-A レセプタクルは選定品によりフットプリントが違う

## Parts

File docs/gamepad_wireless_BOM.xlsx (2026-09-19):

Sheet: 部品表
USBゲームパッド無線化（IM920sL × XIAO RP2040）部品表
青字＝編集可能な入力（数量・単価）。単価はマルツ発注時に最新価格へ更新してください。必須/任意列でフィルタできます。
区分 | 品名 | 型番 | マルツ商品番号 | 必須/任意 | 数量 | 単価(円・税込・参考) | 小計(円) | 価格の根拠 | 備考
送信側 | Seeed XIAO RP2040 | 102010428 | 2229736 | 必須 | 1 | 980 |  | 秋月電子 税込価格(参考) | PIO-USBでUSBホスト（D+=GPIO26/D−=GPIO27）、UARTはGPIO0/1。CPUは240MHz
送信側 | 920MHz無線モジュール（ワイヤーアンテナ） | IM920SL | 2218859 | 必須 | 1 | 4750 |  | マルツ定価(2023年キャンペーン告知) | DC2.1〜3.5V、送信時27mA typ.（XIAOの3V3から供給可）。変換アダプタ経由で接続
送信側 | USB Type-A メスコネクタ（基板直付け・横型） | DS1095-WNR0 相当 | 要検索 | 必須 | 1 | 60 |  | 概算 | 変換基板は使わず基板に直付け。フットプリントは USB_A_CONNFLY_DS1095-WNR0
送信側 | 電解コンデンサ 47µF 10V（C1） | — | 要検索 | 必須 | 1 | 20 |  | 概算 | +5V（ゲームパッド給電）の突入電流対策
送信側 | 抵抗 22Ω 1/4W | — | 要検索 | 必須 | 2 | 10 |  | 概算 | D+/D−の直列抵抗。PIO-USBはタイミング余裕が少ないので実装を推奨
送信側 | モバイルバッテリー（5V USB出力） | — | — | 任意 | 1 | 0 |  | 手持ち流用想定 | XIAOのUSB-Cへ給電。低電流で自動OFFしない機種が望ましい
送信側 | USBケーブル（バッテリー→XIAO USB-C） | — | — | 任意 | 1 | 0 |  | 手持ち流用想定
受信側 | Seeed XIAO RP2040 | 102010428 | 2229736 | 必須 | 1 | 980 |  | 秋月電子 税込価格(参考) | ネイティブUSBでHIDゲームパッドとしてPCに接続
受信側 | 920MHz無線モジュール（ワイヤーアンテナ） | IM920SL | 2218859 | 必須 | 1 | 4750 |  | マルツ定価(2023年キャンペーン告知) | 親機（ノード0001）。UARTはGPIO0/1
受信側 | USB-Cケーブル（PC接続） | — | — | 任意 | 1 | 0 |  | 手持ち流用想定
共通・開発用 | USBインタフェースボード | IM920-USB2 | 要検索 | 任意 | 0 | 2500 |  | マルツ定価(2023年キャンペーン告知) | 不要（XIAOのUSBブリッジで代替）。数量0で集計外
共通 | 積層セラミックコンデンサ 10µF（C2） | — | 要検索 | 必須 | 2 | 20 |  | 概算 | IM920SL VCC 直近（送信機・受信機に各1）
共通 | 積層セラミックコンデンサ 0.1µF（C3） | — | 要検索 | 必須 | 2 | 10 |  | 概算 | IM920SL VCC 直近（各1）
共通 | IM920sL用変換アダプタ（2.54mm J1/J2） | IM920sL-ADP | 要検索 | 必須 | 2 | 1400 |  | 仮置き（旧IM920C-ADPの2023年定価） | IM920sLの20ピンコネクタを2.54mmピッチに変換。販売状況・価格を要確認
共通 | プリント基板（本リポジトリのガーバー） | 100×62mm 2層 t1.6 | — | 必須 | 2 | 400 |  | JLCPCB 等の概算 | 送信機・受信機で同じ基板。hardware/board/gamepad_over_920MHz-gerber.zip を発注。最小 5 枚で送料込 ¥1,500〜4,000
共通 | ピンヘッダ 1×10 2.54mm（ADP 側） | — | 要検索 | 必須 | 4 | 15 |  | 概算 | ADP に実装して基板のソケットへ挿す。1×40 の連結品を切って使う
共通 | ピンソケット 1×10 2.54mm（基板側・ADP 受け） | — | 要検索 | 必須 | 4 | 60 |  | 概算 | ADP は裏面にコネクタが出るので、ソケットで嵩上げする
共通 | ピンソケット 1×7 2.54mm（基板側・XIAO 受け） | — | 要検索 | 必須 | 4 | 45 |  | 概算 | XIAO を抜き差しできるようにする
共通 | ピンヘッダ 1×7 2.54mm（XIAO 側） | — | 要検索 | 任意 | 0 | 15 |  | 概算 | XIAO RP2040 に 2 本付属するので通常は不要。無い場合は 4 本（数量0で集計外）
共通 | M3 ネジ・スペーサー | — | 要検索 | 任意 | 8 | 30 |  | 概算 | 基板四隅の φ3.2 固定穴用。ケースに留める場合
共通・開発用 | ジャンパワイヤ・ブレッドボード | — | — | 任意 | 1 | 0 |  | 手持ち流用想定 | 試作用
将来・距離延長 | 920MHz無線モジュール（外部アンテナタイプ） | IM920SL-XT | 2218863 | 任意 | 0 | 7600 |  | マルツ定価(2023年キャンペーン告知) | 距離不足時にIM920SLと置き換え（数量0で集計外）
 |  |  |  |  |  | 必須部品 合計
 |  |  |  |  |  | 任意部品 合計
 |  |  |  |  |  | 総計
 |  |  |  |  |  | 送料無料までの残額（マルツ：3,000円以上で送料無料）
・マルツ定価はマルツセレクトの2023年8月キャンペーン告知の定価。現在価格は発注時に確認のこと。https://www.marutsu.co.jp/select/list/detail.php?id=1808
・XIAO RP2040・USB-A DIP化基板の単価は秋月電子の税込価格（参考）。マルツでの価格は異なる場合あり。https://akizukidenshi.com/catalog/g/g117044/
・「概算」は汎用品の目安。「手持ち流用想定」は0円で計上。
・マルツ商品番号はマルツ商品ページURL（/pc/i/番号/）から。「要検索」はマルツで同等品を検索。
・送料無料条件（3,000円以上）は検索結果の表示に基づく。発注時に確認のこと。
・Rev.3：タクトスイッチ（SW1）と STATUS LED は削除。設定/ペアリングは XIAO の BOOTSEL、
状態表示は XIAO オンボードのカラー LED を使うため不要。

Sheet: 配線
XIAO RP2040 ピン割り当て（実配線・Rev.3）
基板 | XIAOピン | GPIO | 接続先 | 備考
送信側 | D0 | GPIO26 | USB-A D+ | PIO-USB（pin_dp=26, DPDM）。ファームが起動時に自動判別する
送信側 | D1 | GPIO27 | USB-A D− | D+ の次番号である必要あり
送信側 | 5V | — | USB-A VBUS | USB-C給電時に5V出力
送信側 | GND | — | USB-A GND / ADP J2-9 GND
送信側 | D6 (TX) | GPIO0 | ADP J2-3 RxD（IM920sL pin6） | Serial1
送信側 | D7 (RX) | GPIO1 | ADP J1-4 TxD（pin7） | Serial1
送信側 | 3V3 | — | ADP J1-9 VCC（pin17） | C2 10µF＋C3 0.1µF を近くに
送信側 | D2 | GPIO28 | ADP J1-1 BUSY（pin1） | L=コマンド受付可
送信側 | D3 | GPIO29 | ADP J1-10 RESET（pin19） | L有効・内部10kΩプルアップ
受信側 | USB-C | — | PC | TinyUSB HIDゲームパッド
受信側 | D6 (TX) | GPIO0 | ADP J2-3 RxD（pin6） | Serial1
受信側 | D7 (RX) | GPIO1 | ADP J1-4 TxD（pin7） | Serial1
受信側 | 3V3 / GND | — | ADP J1-9 VCC / J2-9 GND
受信側 | D2 / D3 | GPIO28/29 | BUSY / RESET | 送信側と同じ
共通 | — | — | ADP その他のピン | 未接続（IO8〜IO10はオープンでデータモード）
共通 | — | — | — | Arduino-Pico で CPU Speed=240MHz（PIO-USB の要件、送信側のみ必須）
根拠：IM920sL 取扱説明書 Rev.1.5 表15、IM920sL-ADP 製品資料 Rev.1.0 回路図。
共通 |  |  | 設定/ペアリング＝XIAO の BOOTSEL ボタン | SW1 は廃止（起動後 5 秒の受付ウィンドウ、または赤点滅中に長押し）
共通 |  |  | 状態表示＝XIAO オンボードのカラー LED | NeoPixel(GPIO12/電源GPIO11) と三色 LED(R17/G16/B25)。STATUS LED は廃止

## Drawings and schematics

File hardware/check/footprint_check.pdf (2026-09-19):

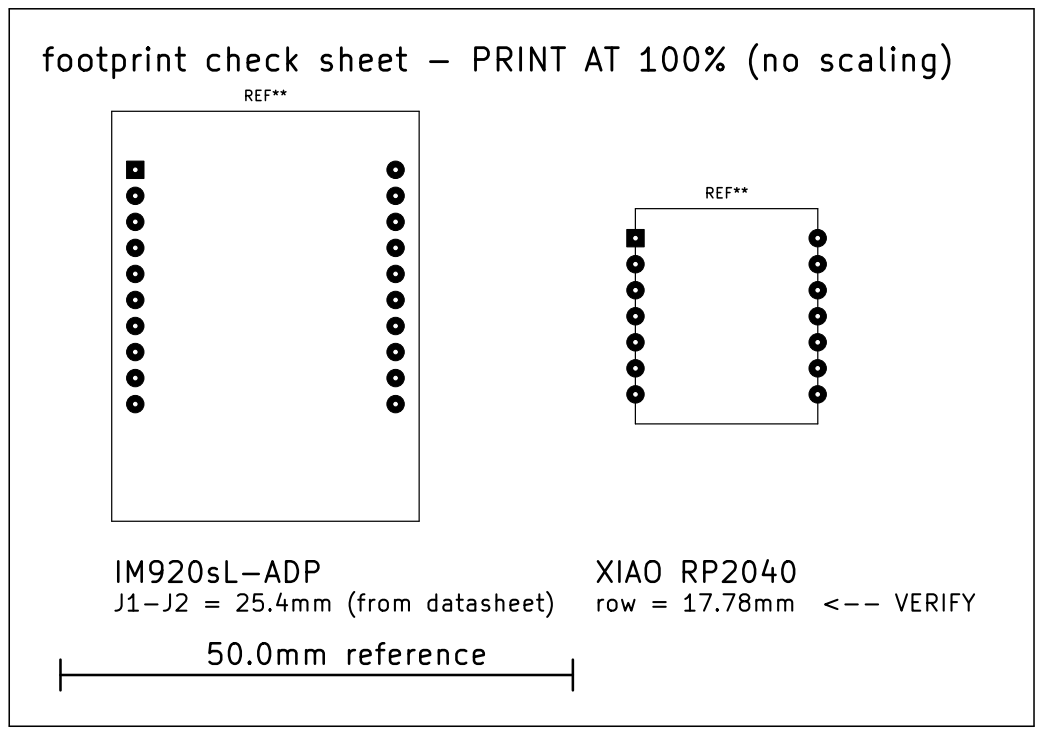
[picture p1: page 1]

footprint check sheet - PRINT AT 100% (no scaling)

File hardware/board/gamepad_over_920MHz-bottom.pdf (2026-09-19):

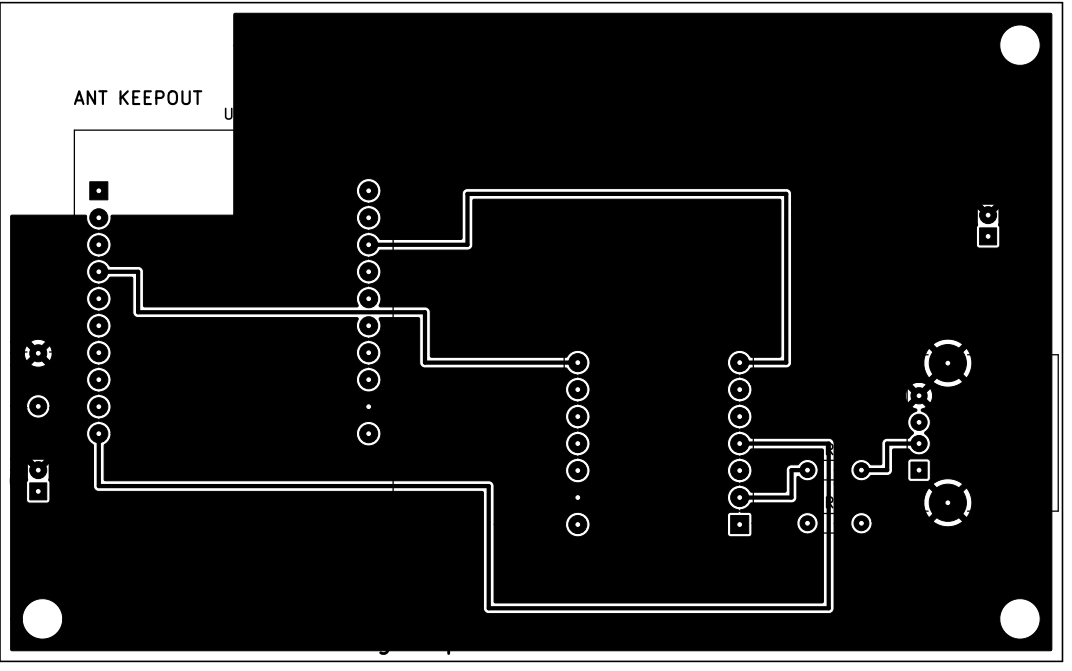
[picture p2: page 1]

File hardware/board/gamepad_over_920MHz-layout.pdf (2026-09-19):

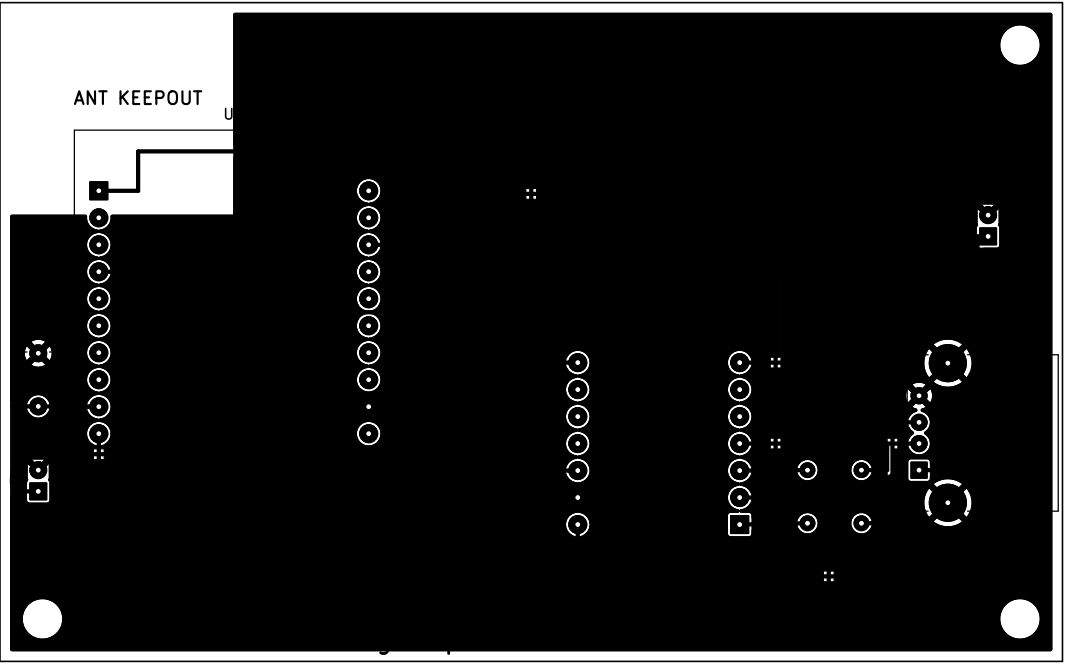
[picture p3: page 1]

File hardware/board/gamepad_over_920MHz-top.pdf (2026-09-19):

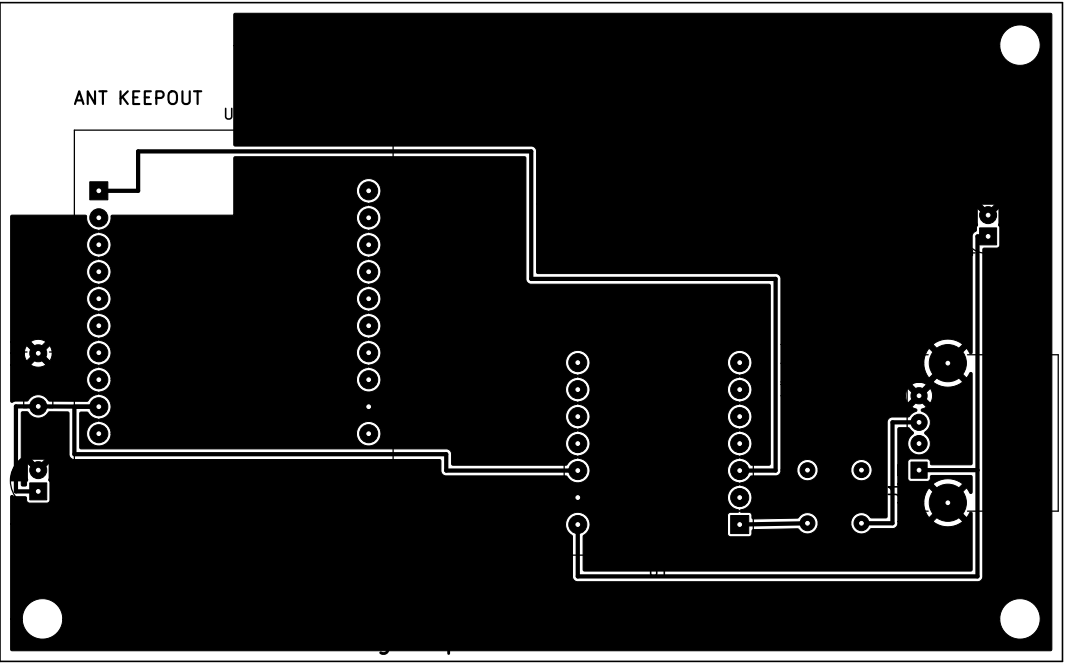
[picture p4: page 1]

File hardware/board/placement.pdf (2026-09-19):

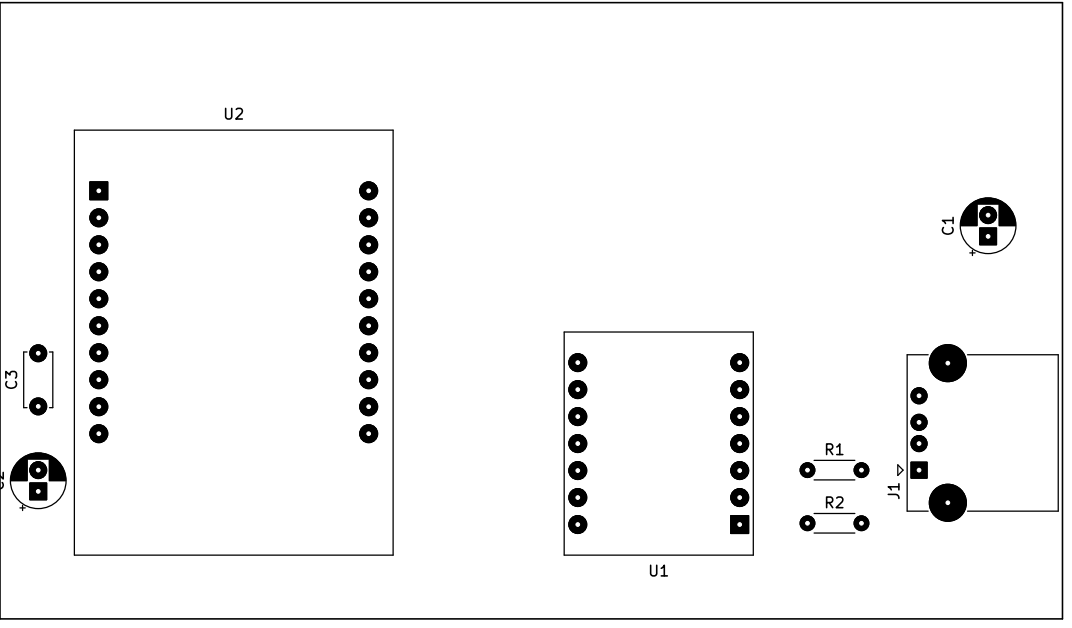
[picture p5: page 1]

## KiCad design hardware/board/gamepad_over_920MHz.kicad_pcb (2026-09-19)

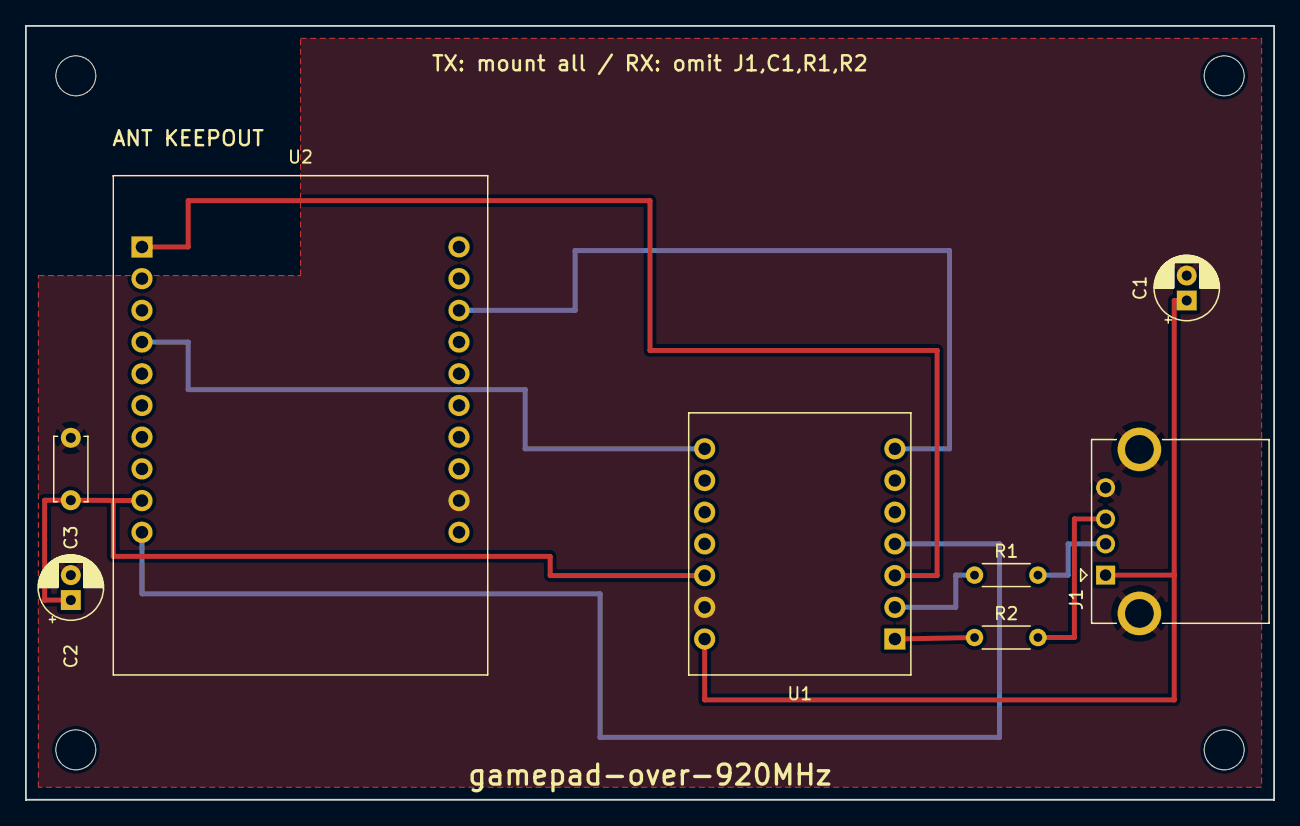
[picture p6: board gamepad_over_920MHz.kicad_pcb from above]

Board: 2 copper layers, 100.0 x 62.0 mm, 12 parts (0 on the bottom side), 11 nets.

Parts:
C1, C2: CP_Radial_D5.0mm_P2.00mm
C3: C_Disc_D5.0mm_W2.5mm_P5.00mm
H1, H2, H3, H4: MountingHole_3.2mm_M3
J1: USB_A_CONNFLY_DS1095-WNR0
R1, R2: R_Axial_DIN0204_L3.6mm_D1.6mm_P5.08mm_Horizontal
U1: XIAO_RP2040
U2: IM920sL_ADP

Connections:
+3V3: C2.1, C3.1, U1.10, U2.9
+5V: C1.1, J1.1, U1.8
GND: C1.2, C2.2, C3.2, J1.4, J1.5, U1.9, U2.19
IM_BUSY: U1.3, U2.1
IM_RESET: U1.4, U2.10
IM_RXD: U1.7, U2.13
IM_TXD: U1.14, U2.4
USB_DM: R1.1, U1.2
USB_DM_CON: J1.2, R1.2
USB_DP: R2.1, U1.1
USB_DP_CON: J1.3, R2.2

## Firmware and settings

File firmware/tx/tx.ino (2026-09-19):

// tx.ino — 送信機（ゲームパッド側）
//   XIAO RP2040 が PIO-USB で USB ゲームパッドのホストになり、
//   状態を IM920sL（920MHz）で受信機へ送る。
//
//   コア1: PIO-USB ホスト（D+ = GPIO27, D- = GPIO26。実配線に合わせて DMDP）
//   コア0: IM920sL への送信と、USB-C の CDC コンソール
//
//   ビルド: Seeed XIAO RP2040 / USB Stack = Adafruit TinyUSB / CPU 120MHz
//           （build.sh を使うか、下記 FQBN で arduino-cli compile）
//   fqbn: rp2040:rp2040:seeed_xiao_rp2040:usbstack=tinyusb,freq=120
#define IM_ROLE_TX

#include "pio_usb.h"
#include "Adafruit_TinyUSB.h"
#include <pico/multicore.h>
#include <EEPROM.h>
#include <pico/unique_id.h>
#include <pico/platform.h>

#include "packet.h"
#include "im920sl_config.h"
#include "hid_gamepad_map.h"
#include "status_led.h"
#include "boot_button.h"
#include "wg_dbg.h"
#include "im920_diag.h"

// ---- USB-A の D+/D- の向き ----
// 回路図 Rev.2 は「GPIO27 = D+, GPIO26 = D-」だが、実配線が逆の個体もあるため
// 起動時に自動判別する（機器のプルアップで H になっている側が D+）。
// 手で決めるときは CDC コンソールの `usbpin 26` / `usbpin 27` / `usbpin auto`。
#define PIN_USB_HOST_DP_DEFAULT  27
#define TX_CFG_ADDR   0
#define TX_CFG_MAGIC  0x57475431UL   // 'WGT1'
// noNeo: NeoPixel を使わない（三色 LED だけで状態表示する）。
// NeoPixel と PIO-USB は PIO を共有するため、core1 停止の切り分け用に切れるようにした。
struct TxCfg { uint32_t magic; uint8_t dpPin; uint8_t noNeo; uint8_t rsv[2]; };
// ウォッチドッグ／ソフトリセットでは RAM の内容が残るので、
// 「異常再起動だった」ことを次の起動に伝えてボタン受付ウィンドウを飛ばす。
#define WG_FASTBOOT_MAGIC 0x57474642UL   // 'WGFB'
static __uninitialized_ram(uint32_t) g_fastBootFlag;

// ---- ブラックボックス ----
// 赤点滅や自動再起動が起きても、再起動でカウンタが消えて原因が追えなかった。
// __uninitialized_ram はソフトリセットでは保持されるので、ここに記録を残す。
// （電源を抜くと magic が壊れてクリアされる＝手動の電源断と自動再起動を区別できる）
#define WG_BB_MAGIC 0x57474242UL         // 'WGBB'
enum {                                   // 再起動・赤点滅の理由
  WG_R_NONE = 0, WG_R_CORE1, WG_R_DESC, WG_R_MANUAL,
  WG_R_PAD, WG_R_HOST, WG_R_HB, WG_R_RXDOWN,
};
typedef struct {
  uint32_t magic;
  uint32_t boots;           // ソフト再起動の回数
  uint32_t rebootReason;    // 最後の自動再起動の理由
  uint32_t upMs;            // そのときの稼働時間
  uint32_t reports, ok, ng; // そのときの主要カウンタ
  uint32_t hbAgeMs;         // 最後にハートビートを受けてからの経過
  uint32_t redCount;        // 赤点滅に落ちた回数（累積）
  uint32_t redPad, redHost, redHb, redRx;   // その原因別の内訳
  uint32_t lastRedMs;       // 直近に赤へ落ちた時刻
  uint32_t savedCh;         // 自動再起動の直前に使っていたチャンネル
  // core1 が固まった瞬間の PIO-USB の状態（根本原因を追うための証拠）
  uint32_t stallInts, stallEpErr, stallEpStall;
  uint8_t  stallInit, stallConn, stallFs, stallSusp;
  uint8_t  stallStage, stallNeedArm, stallDevAddr, stallValid;
} WgBlackBox;   // __uninitialized_ram はマクロ引数をセクション名に使うので
                // 空白を含まない 1 語の型名が必要
static __uninitialized_ram(WgBlackBox) g_bb;

static TxCfg   g_cfg;
static uint8_t g_usbDp = PIN_USB_HOST_DP_DEFAULT;
static const char *g_usbDpSrc = "default";

// ---- 送信のタイミング ----
// 4s モード（ch31〜45）は「送信休止時間 52ms 以上」が電波法上の規定で、
// 満たさないと 3.9 秒ごとに強制休止が入り TXDA が NG を返す（取説 Rev.1.5 §7-3）。
// 実測した NG 率（12 バイト・各 80〜150 回、キャリアセンス約 6ms ＋ 送信 6ms）:
//   55ms=20%  65ms=17.5%  75ms=12.5%  90ms=8%  120ms=4%  150ms=0%
// NG は一度も連続しなかった（90/120ms で全て単発）ので、欠落は最悪 2 周期分。
// 90ms なら 180ms で、受信側フェイルセーフ 300ms に余裕がある。
// ※ 暗号化を有効にすると 1 パケットが 24 バイト増えるので、その場合は要再測定。
// NG は単発でしか起きないことが実測で分かったので（次の周期で回復し、受信側
// フェイルセーフ 300ms には届かない）、間隔を延ばすより詰めたほうが実効レートが高い。
// 90ms に延ばした実測では NG 率 9.2%→7.5% と引き換えに
// 実効更新レートが 8.8/s→6.5/s まで落ちたため、30/60ms に戻した。
static uint32_t TX_MIN_INTERVAL = 30;    // 最短送信間隔 [ms]（rate コマンドで変更可）
static uint32_t TX_KEEPALIVE    = 60;    // 変化がなくても送る間隔 [ms]
static const uint32_t TX_INFO_PERIOD  = 2000;  // Info パケットの間隔 [ms]
// 送信機のモジュールは半二重で、自分が送信している間は受信できない。
// 実測（2026-09-19）では送信間隔によってハートビートの取りこぼしが大きく変わる:
//   送信 60ms（パッド静止）… 欠落 6.6%
//   送信 30ms（操作中）  … 欠落 29.5%
// ハートビートは 2 秒周期なので、5 秒では 2 回連続の欠落（操作中で 8.7%）で
// リンク断と誤判定していた。平均 20〜30 秒に 1 回、動作中に突然赤点滅する原因。
// 15 秒あれば 7 回連続の欠落が必要になり（0.02%）、実用上起きない。
// ※ ロボットの保護は受信側の 300ms フェイルセーフが行うので、
//    送信側のリンク判定を鈍くしても安全性は落ちない。
static const uint32_t HB_TIMEOUT_MS   = 15000;

extern "C" void wgPioState(int *initialized, int *connected, int *fullspeed,
                           int *suspended, unsigned long *ints,
                           unsigned long *epError, unsigned long *epStalled);
extern "C" void wgPioForceReconnect(void);

Adafruit_USBH_Host USBHost;
static WgStatusLed g_led;
static WgBootButton g_btn;

// ---- コア間で共有する状態（mutex で保護）----
static mutex_t   g_mtx;
static WgState   g_state;            // 最新のパッド状態
static WgInfo    g_info;             // パッドの構成
static bool      g_infoValid = false;
static bool      g_padConnected = false;
static uint8_t   g_raw[64];          // dump 用の生レポート
static uint8_t   g_rawLen = 0;
static uint32_t  g_rawSeq = 0;
static uint32_t  g_reportCount = 0;

// ---- USB ホストの記録（コア1 で積み、コア0 で表示する）----
struct UsbEvent {
  uint8_t  kind;          // 1=device mount 2=device umount 3=HID mount 4=HID umount 5=HID 非対応
  uint8_t  addr, inst;
  uint16_t vid, pid;
  uint16_t descLen;
  uint8_t  axisMask, buttons, hat;
};
static UsbEvent g_ev[12];
static uint8_t  g_evHead = 0, g_evTail = 0;
static uint8_t  g_descBuf[256];
static uint16_t g_descBufLen = 0;
static uint32_t g_mountCount = 0;

static void pushEvent(const UsbEvent &e) {
  mutex_enter_blocking(&g_mtx);
  uint8_t next = (uint8_t)((g_evHead + 1) % (uint8_t)(sizeof(g_ev) / sizeof(g_ev[0])));
  if (next != g_evTail) { g_ev[g_evHead] = e; g_evHead = next; }
  mutex_exit(&g_mtx);
}

// ---- コア1 だけが触る ----
static WgHidMap  g_map;
static uint8_t   g_devAddr = 0, g_devInst = 0;

// ---- コア0 だけが触る ----
static volatile bool g_core1Go = false;
static bool     g_dump = false;
static uint32_t g_okCount = 0, g_ngCount = 0, g_shortReports = 0;
static uint32_t g_ngBusy = 0, g_ngResp = 0, g_ngNo = 0;
static uint32_t g_txMinInterval = TX_MIN_INTERVAL;   // rate コマンドで変更
static uint32_t g_lastOkMs = 0;
static uint32_t g_rawSeqShown = 0;
static uint32_t g_lastHbMs = 0, g_hbCount = 0;
// コア1（USB ホスト）の生存監視。
// コア1 が死んでもコア0 は動き続けるため、ウォッチドッグは餌をもらって発火しない。
// その間パッドは「接続中」のまま中立値が送られ、LED も緑のままになってしまう
// （実機で発生）。遠隔操縦では最悪の故障モードなので、明示的に見張る。
static uint32_t g_hostTickSeen = 0, g_hostTickMs = 0;
static bool     g_hostAlive = true;
static uint32_t g_hostStallCount = 0;
static uint32_t g_lockFail = 0;

// ---- チャンネル選定（起動直後に 1 回だけ）----
// ch31 は待ち合わせ用。起動時は AutoConfig が必ず 31 に戻す（Flash の既定値）。
// リンクが確立したら 31〜45 を走査し、最も静かなチャンネルへ受信機ごと移動する。
// 通知が届かず片方だけ移動しても、双方「一定時間受信が無ければ 31 へ戻る」ので復帰できる。
#define WG_CH_HOME      31
#define WG_CH_LAST      45
// 待ち合わせ（ch31）に戻る判定もハートビート頼りなので、同じ理由で延ばす。
// 12 秒＝6 回連続の欠落（操作中で 0.07%／2 秒ごと）で誤って再走査に入り、
// 受信機を取り残して本当の通信断を作っていた。30 秒なら 15 回連続が必要。
static const uint32_t CH_REVERT_MS = 30000;  // これだけ応答が無ければ待ち合わせに戻る
static const int      CH_MAX_TRIES = 3;      // 移動を試みる回数の上限

static uint8_t  g_curCh = WG_CH_HOME;
static bool     g_chScanned = false;
static bool     g_fastBootRecover = false;   // 異常再起動からの復帰で起動したか
static int      g_chTries = 0;
static int8_t   g_chRssi[WG_CH_LAST - WG_CH_HOME + 1];
static const uint32_t HOST_STALL_MS  = 1000;   // これだけ進まなければ異常とみなす
// core1 は常時回っているので、数秒止まっていれば確実に死んでいる。
// 10 秒待つと、再起動と再走査を合わせて実測 21 秒の通信断になっていた（2026-09-19）。
static const uint32_t HOST_REBOOT_MS = 3000;   // これだけ続いたら再起動して復帰を試みる
static int8_t   g_hbRssiHere = 0;    // 送信機が見たハートビートの RSSI
static int8_t   g_hbRssiThere = 0;   // 受信機が見ている RSSI（ハートビートの中身）
static bool     g_rxReceiving = false;  // 受信機が「前方向を受信できている」と言っているか
// ハートビートがどこで落ちているかの切り分け用
static uint32_t g_rxLines = 0, g_rxLinesParsed = 0, g_rxFromRx = 0, g_hbBad = 0;
static uint8_t  g_seq = 0;

// ---- 列挙の経過を RAM のリングバッファに溜める ----
// USB ホストのコールバックはコア1 で呼ばれるので Serial を直接触らず、
// ここに溜めて CDC コンソールの `log` コマンドで読む。
// （TinyUSB 本体の CFG_TUSB_DEBUG は log_printf が Serial1＝IM920sL に出るので使わない）
#define WG_LOG_SIZE 12288
static char     g_logBuf[WG_LOG_SIZE];
static volatile uint16_t g_logW = 0;
static volatile bool     g_logWrapped = false;
// ログを CDC に出すと、その通信自体が TinyUSB デバイス側のログを生んで
// バッファを流してしまう。コンソール処理の間はデバイススタックのログを止める。
static volatile bool     g_logMute = false;

static void wgLogPut(const char *s, int n) {
  for (int i = 0; i < n; i++) {
    g_logBuf[g_logW] = s[i];
    g_logW = (uint16_t)((g_logW + 1) % WG_LOG_SIZE);
    if (g_logW == 0) g_logWrapped = true;
  }
}

// TinyUSB のデバッグ出力の受け皿（wg_dbg.h 参照）
size_t WgDbgStream::write(uint8_t c) {
  if (!g_logMute) wgLogPut((const char *)&c, 1);
  return 1;
}
size_t WgDbgStream::write(const uint8_t *buf, size_t n) {
  if (!g_logMute) wgLogPut((const char *)buf, (int)n);
  return n;
}
WgDbgStream wgDbgStream;

static int wgLog(const char *fmt, ...) {
  char tmp[192];
  va_list ap;
  va_start(ap, fmt);
  int n = vsnprintf(tmp, sizeof(tmp), fmt, ap);
  va_end(ap);
  if (n > 0) wgLogPut(tmp, n > (int)sizeof(tmp) - 1 ? (int)sizeof(tmp) - 1 : n);
  return n;
}

static void printLog() {
  g_logMute = true;
  Serial.println(F("---- log ----"));
  if (g_logWrapped)
    for (uint16_t i = g_logW; i < WG_LOG_SIZE; i++) Serial.write(g_logBuf[i]);
  for (uint16_t i = 0; i < g_logW; i++) Serial.write(g_logBuf[i]);
  Serial.println(F("\n---- end ----"));
  Serial.flush();
  g_logMute = false;
}

static const uint32_t WDT_MS = 4000;      // これだけループが止まったら再起動

static void ledTick() {
  g_led.task();
  rp2040.wdt_reset();                      // ブロッキング処理中も餌やりする
}

// 送信処理の合間に退避された受信行を拾う
static void pollHeartbeat() {
  char line[96];
  while (im920StashTake(line, sizeof(line))) {
    g_rxLines++;
    uint16_t node = 0;
    int8_t   rssi = 0;
    uint8_t  data[40];
    size_t   len = 0;
    if (!im920ParseRx(line, node, rssi, data, sizeof(data), len)) continue;
    g_rxLinesParsed++;
    if (node != WG_NODE_RX) continue;
    g_rxFromRx++;
    WgHeartbeat h;
    if (!wgHbDecode(data, len, &h)) { g_hbBad++; continue; }
    g_lastHbMs = millis();
    g_hbCount++;
    g_hbRssiHere = rssi;
    g_hbRssiThere = h.rssi;
    g_rxReceiving = (h.flags & WG_HB_RXOK) != 0;
  }
}

static char g_lastBadResp[40] = "";

// 各チャンネルの雑音を測る。値が大きい（0 に近い）ほど混んでいる
static uint8_t scanChannels() {
  Serial.println(F("空きチャンネルを探しています..."));
  uint8_t best = WG_CH_HOME;
  int8_t  bestRssi = 0;
  for (uint8_t ch = WG_CH_HOME; ch <= WG_CH_LAST; ch++) {
    if (!im920SetChannelVolatile(ch)) continue;
    int8_t worst = -128;
    for (int i = 0; i < 6; i++) {          // 一瞬の空きに騙されないよう最悪値を採る
      int8_t v = im920ReadRssi();
      if (v > worst) worst = v;
      delay(8);
      ledTick();
    }
    g_chRssi[ch - WG_CH_HOME] = worst;
    if (ch == WG_CH_HOME || worst < bestRssi) { bestRssi = worst; best = ch; }
  }
  im920SetChannelVolatile(WG_CH_HOME);      // 通知のため待ち合わせに戻る
  Serial.print(F("  RSSI: "));
  for (uint8_t ch = WG_CH_HOME; ch <= WG_CH_LAST; ch++)
    Serial.printf("%u:%d ", ch, g_chRssi[ch - WG_CH_HOME]);
  Serial.printf("\n  選択: ch%u (%ddBm)\n", best, bestRssi);
  return best;
}

// 移動先を数回通知してから自分も移動する
static void announceAndMove(uint8_t ch) {
  uint8_t buf[WG_CHCMD_LEN];
  wgChCmdEncode(ch, buf);
  for (int i = 0; i < 6; i++) {
    im920SendEx(buf, sizeof(buf));
    delay(40);
    ledTick();
  }
  if (im920SetChannelVolatile(ch)) {
    g_curCh = ch;
    Serial.printf("ch%u へ移動しました\n", ch);
  } else {
    Serial.println(F("チャンネル移動に失敗しました"));
  }
}

static void countSend(int r) {
  if (r == IM_SEND_NG) {
    strncpy(g_lastBadResp, im920LastResponse().c_str(), sizeof(g_lastBadResp) - 1);
    g_lastBadResp[sizeof(g_lastBadResp) - 1] = '\0';
  }
  switch (r) {
    case IM_SEND_OK:     g_okCount++; g_lastOkMs = millis(); break;
    case IM_SEND_BUSY:   g_ngBusy++;  g_ngCount++; break;
    case IM_SEND_NG:     g_ngResp++;  g_ngCount++; break;
    default:             g_ngNo++;    g_ngCount++; break;
  }
}

// 線の静電容量をおおまかに測る（断線の切り分け用）
//   一度 L に落としてから内部プルアップで離し、H になるまでのループ回数を数える。
//   USB ケーブル＋機器がぶら下がっていれば 50〜100pF ついて回数が大きくなる。
//   基板パターンだけ（断線）なら数 pF で、ほぼ即座に H になる。
static uint32_t wgRiseCount(uint8_t pin) {
  uint32_t sum = 0;
  const int N = 32;                        // 分解能を上げるため合計で返す
  for (int k = 0; k < N; k++) {
    pinMode(pin, OUTPUT);
    digitalWrite(pin, LOW);
    delayMicroseconds(300);
    uint32_t n = 0;
    noInterrupts();
    pinMode(pin, INPUT_PULLUP);
    while (!digitalRead(pin) && n < 200000) n++;
    interrupts();
    pinMode(pin, INPUT);
    sum += n;
    delayMicroseconds(300);
  }
  return sum;
}

static uint32_t g_rise26 = 0, g_rise27 = 0, g_riseOpen = 0;
static void measureUsbLines() {
  g_rise26   = wgRiseCount(26);
  g_rise27   = wgRiseCount(27);
  g_riseOpen = wgRiseCount(6);     // 回路図で未接続のピン（基準）
}

// 機器のプルアップで H になっている側が D+。判別できなければ 0
// PIO-USB を起動する前（＝誰も線を駆動していない状態）に 1 回だけ実行する
static int g_p26pd = -1, g_p27pd = -1, g_p26pu = -1, g_p27pu = -1;
static uint8_t detectDpPin() {
  pinMode(26, INPUT_PULLDOWN);
  pinMode(27, INPUT_PULLDOWN);
  delay(20);
  g_p26pd = digitalRead(26); g_p27pd = digitalRead(27);
  pinMode(26, INPUT_PULLUP);
  pinMode(27, INPUT_PULLUP);
  delay(20);
  g_p26pu = digitalRead(26); g_p27pu = digitalRead(27);
  pinMode(26, INPUT);
  pinMode(27, INPUT);
  if (g_p26pd && !g_p27pd) return 26;      // 26 側だけが強く H = そこに機器のプルアップ
  if (g_p27pd && !g_p26pd) return 27;
  return 0;
}

// バスが動いているか（PIO-USB がリセットや列挙を試みていれば変化する）
static void printLines(uint8_t a, uint8_t b, bool inv) {
  uint32_t t0 = micros();
  uint32_t nA = 0, nB = 0, hiA = 0, hiB = 0, n = 0;
  int la = inv ? !gpio_get(a) : gpio_get(a), lb = inv ? !gpio_get(b) : gpio_get(b);
  while (micros() - t0 < 200000) {
    int va = inv ? !gpio_get(a) : gpio_get(a), vb = inv ? !gpio_get(b) : gpio_get(b);
    if (va != la) { nA++; la = va; }
    if (vb != lb) { nB++; lb = vb; }
    hiA += (uint32_t)va; hiB += (uint32_t)vb; n++;
  }
  Serial.printf("  200ms の観測: GPIO%u 変化%lu回 H率%lu%%  GPIO%u 変化%lu回 H率%lu%%\n",
                a, (unsigned long)nA, (unsigned long)(hiA * 100 / n),
                b, (unsigned long)nB, (unsigned long)(hiB * 100 / n));
}

static void cfgLoad() {
  EEPROM.get(TX_CFG_ADDR, g_cfg);
  if (g_cfg.magic != TX_CFG_MAGIC ||
      (g_cfg.dpPin != 0 && g_cfg.dpPin != 26 && g_cfg.dpPin != 27)) {
    g_cfg.magic = TX_CFG_MAGIC;
    g_cfg.dpPin = 0;                       // 0 = 自動判別
    g_cfg.noNeo = 0;
    memset(g_cfg.rsv, 0, sizeof(g_cfg.rsv));
  }
}

static void cfgSave() {
  g_cfg.magic = TX_CFG_MAGIC;
  EEPROM.put(TX_CFG_ADDR, g_cfg);
  EEPROM.commit();
}

// =====================================================================
// コア1: PIO-USB ホスト
// =====================================================================
static void __not_in_flash_func(core1WaitForGo)() {
  while (!g_core1Go) { tight_loop_contents(); }
}

static volatile uint32_t g_hostTicks = 0;
static volatile uint8_t  g_hostStage = 0;   // 1=待機解除 2=configure 済 3=begin 済

void setup1() {
  core1WaitForGo();                       // 起動直後の BOOTSEL 判定が終わるまで待つ
  g_hostStage = 1;
  pio_usb_configuration_t pio_cfg = PIO_USB_DEFAULT_CONFIG;
  pio_cfg.pin_dp = g_usbDp;
  // D+ = GPIO27 なら D- = 26（DMDP）、D+ = GPIO26 なら D- = 27（DPDM）
  pio_cfg.pinout = (g_usbDp == 27) ? PIO_USB_PINOUT_DMDP : PIO_USB_PINOUT_DPDM;
  USBHost.configure_pio_usb(1, &pio_cfg);
  g_hostStage = 2;
  USBHost.begin(1);
  g_hostStage = 3;
}

// tuh_hid_receive_report() が失敗したまま放置すると、以後レポートが一切
// 届かなくなる。失敗したら次のループで再試行する。
static volatile bool g_needArm = false;
static volatile uint32_t g_needArmSinceMs = 0;
static uint32_t g_armFail = 0;

static void armReport(uint8_t addr, uint8_t inst) {
  if (!tuh_hid_receive_report(addr, inst)) {
    g_armFail++;
    if (!g_needArm) g_needArmSinceMs = millis();
    g_needArm = true;
  } else {
    g_needArm = false;
  }
}

void loop1() {
  g_hostTicks++;
  USBHost.task();
  if (g_needArm && g_devAddr) {
    static uint32_t last = 0;
    uint32_t now = millis();
    if (now - last >= 10) { last = now; armReport(g_devAddr, g_devInst); }
  }
}

extern "C" {
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
void loop() {
  static WgState lastSent;
  static bool     haveLast = false;
  static uint32_t lastSendMs = 0, lastInfoMs = 0;

  rp2040.wdt_reset();
  pollConsole();
  pollHeartbeat();
  pollPioState();
  pollEvents();
  pollDump();
  g_led.task();

  uint32_t now = millis();

  // LED: パッドが繋がっていて、直近に TXDA が通っていれば緑
  //
  // ⚠ ここは mutex_enter_blocking にしない。
  //   core1 がロックを保持したまま死ぬとコア0 が永久に待ち、ウォッチドッグ（コア0 が
  //   餌をやる）も止まって 4 秒後に再起動になる。受信機は 300ms で中立に落ちるので
  //   安全側ではあるが、復帰に 10 秒以上かかり、下の生存監視にも到達しない。
  //   タイムアウト付きで取り、取れなければ core1 異常として degrade 経路へ進む。
  bool padConn = false;
  bool lockOk = mutex_enter_timeout_ms(&g_mtx, 20);
  if (lockOk) {
    padConn = g_padConnected;
    mutex_exit(&g_mtx);
  } else {
    g_lockFail++;
    g_hostTickMs = (g_hostTickMs > HOST_STALL_MS) ? (millis() - HOST_STALL_MS - 1) : 0;
  }
  if (g_hbCount && (now - g_lastHbMs) >= HB_TIMEOUT_MS) g_rxReceiving = false;

  // ---- チャンネル選定と復帰 ----
  // リンクが確立してから走査する（受信機が待ち合わせ ch にいることを確かめてから移動する）
  if (!g_chScanned && g_hbCount > 0 && g_chTries < CH_MAX_TRIES) {
    g_chScanned = true;
    g_chTries++;
    uint8_t best = scanChannels();
    if (best != g_curCh) announceAndMove(best);
  }
  // 移動先で応答が無ければ待ち合わせチャンネルへ戻る（片方だけ移動した場合の復帰）
  if (g_curCh != WG_CH_HOME && g_hbCount && (now - g_lastHbMs) > CH_REVERT_MS) {
    Serial.printf("[%lu] ch%u で応答が無いため ch%u に戻ります\n",
                  (unsigned long)now, g_curCh, WG_CH_HOME);
    if (im920SetChannelVolatile(WG_CH_HOME)) g_curCh = WG_CH_HOME;
    g_lastHbMs = now;                       // すぐに再判定しない
    g_chScanned = false;                    // 再度やり直す（CH_MAX_TRIES まで）
  }

  // ---- コア1 の生存確認 ----
  if (g_hostStage >= 3) {
    uint32_t t = g_hostTicks;
    if (t != g_hostTickSeen) { g_hostTickSeen = t; g_hostTickMs = now; }
    else if (g_hostTickMs == 0) { g_hostTickMs = now; }
    bool alive = (now - g_hostTickMs) < HOST_STALL_MS;
    if (!alive && g_hostAlive) {
      g_hostAlive = false;
      g_hostStallCount++;
      {   // 固まった瞬間のレジスタを残す。core1 は止まっているが core0 からは読める
        int i2, c2, f2, s2; unsigned long in2, ee2, es2;
        wgPioState(&i2, &c2, &f2, &s2, &in2, &ee2, &es2);
        g_bb.stallInts = in2; g_bb.stallEpErr = ee2; g_bb.stallEpStall = es2;
        g_bb.stallInit = i2; g_bb.stallConn = c2; g_bb.stallFs = f2; g_bb.stallSusp = s2;
        g_bb.stallStage = g_hostStage; g_bb.stallNeedArm = g_needArm ? 1 : 0;
        g_bb.stallDevAddr = g_devAddr; g_bb.stallValid = 1;
      }
      Serial.printf("[%lu] USB ホスト（コア1）が停止。パッドを切断扱いにします\n",
                    (unsigned long)now);
    } else if (alive && !g_hostAlive) {
      g_hostAlive = true;
      Serial.printf("[%lu] USB ホストが復帰\n", (unsigned long)now);
    }
    // レポートの再アームが戻らない＝パッドからの入力が止まっている。
    // core1 は回っているので上の生存監視では捕まらない（レビュー指摘 H-4）。
    if (g_needArm && (now - g_needArmSinceMs) > 500 && padConn) {
      Serial.printf("[%lu] パッドのレポート受信が復帰しません。切断扱いにします\n",
                    (unsigned long)now);
      if (mutex_enter_timeout_ms(&g_mtx, 20)) {
        wgStateNeutral(&g_state);
        g_padConnected = false;
        g_infoValid = false;
        mutex_exit(&g_mtx);
      }
      padConn = false;
    }

    if (!g_hostAlive) {
      // 受信機をフェイルセーフに入れる（中立＋flags.bit0=0）
      if (mutex_enter_timeout_ms(&g_mtx, 20)) {
        wgStateNeutral(&g_state);
        g_padConnected = false;
        g_infoValid = false;
        mutex_exit(&g_mtx);
      }
      padConn = false;
      if (now - g_hostTickMs > HOST_REBOOT_MS) {
        Serial.println(F("復帰しないため再起動します"));
        g_bb.rebootReason = WG_R_CORE1;         // 次の起動で読めるように記録
        g_bb.upMs = now;
        g_bb.reports = g_reportCount;
        g_bb.ok = g_okCount;
        g_bb.ng = g_ngCount;
        g_bb.hbAgeMs = g_hbCount ? (now - g_lastHbMs) : 0xFFFFFFFFUL;
        g_bb.savedCh = g_curCh;       // 受信機はこの ch に残るので、戻って再会合を省く
        Serial.flush();
        g_fastBootFlag = WG_FASTBOOT_MAGIC;
        delay(50);
        rp2040.reboot();
      }
    }
  }

  // 緑は「受信機からハートビートが届いている」＝本当にリンクが生きているときだけ。
  // TXDA の OK はモジュールが受理しただけで、届いたことを意味しない。
  if (g_led.mode() != WG_LED_BRIDGE && g_led.mode() != WG_LED_PAIRING) {
    // 緑の条件: パッドが生きている ＋ USB ホストが生きている ＋
  //           受信機からハートビートが届いている ＋ 受信機が前方向を受信できている
  bool hbFresh = g_hbCount && (now - g_lastHbMs) < HB_TIMEOUT_MS;
  bool linkOk = padConn && g_hostAlive && hbFresh && g_rxReceiving;
    // 緑→赤に落ちた瞬間だけ、原因を記録する（再起動しても残る）
    if (!linkOk && g_led.mode() == WG_LED_CONNECTED) {
      g_bb.redCount++;
      g_bb.lastRedMs = now;
      uint32_t why = WG_R_NONE;
      if (!padConn)            { g_bb.redPad++;  why = WG_R_PAD; }
      else if (!g_hostAlive)   { g_bb.redHost++; why = WG_R_HOST; }
      else if (!hbFresh)       { g_bb.redHb++;   why = WG_R_HB; }
      else                     { g_bb.redRx++;   why = WG_R_RXDOWN; }
      Serial.printf("[%lu] 赤点滅へ: %s\n", (unsigned long)now, wgReasonName(why));
    }
    g_led.set(linkOk ? WG_LED_CONNECTED : WG_LED_DISCONNECTED);
  }

  // ⚠ 送信機では実行中に BOOTSEL を読まない。
  //   BOOTSEL の読み取りは rp2040.idleOtherCore() でコア1 を止め、XIP を一時停止する。
  //   コア1 では PIO-USB が動いているため、これが噛み合わないとコア1 が復帰せず、
  //   コア0 が待ち続けてデッドロックする（実機で発生。LED が緑のまま固まった）。
  //   ボタンを使えるのは、コア1 を起動する前の「起動直後の受付ウィンドウ」だけ。
  //   受信機（PIO-USB を使わない）では実行中も読んで問題ない。
  (void)g_btn;

  if (now - lastSendMs < g_txMinInterval) return;

  // Info パケット（受信機が HID ディスクリプタを合わせるために使う）
  WgState cur;
  WgInfo  info;
  bool    infoValid = false;
  if (!mutex_enter_timeout_ms(&g_mtx, 20)) { g_lockFail++; return; }
  cur = g_state;
  info = g_info;
  infoValid = g_infoValid;
  mutex_exit(&g_mtx);

  if (infoValid && (now - lastInfoMs >= TX_INFO_PERIOD)) {
    uint8_t buf[WG_INFO_LEN];
    wgInfoEncode(&info, buf);
    countSend(im920SendEx(buf, sizeof(buf)));
    lastInfoMs = now;
    lastSendMs = millis();
    return;
  }

  bool changed = !haveLast || !wgStateEqual(&cur, &lastSent);
  if (!changed && (now - lastSendMs < TX_KEEPALIVE)) return;

  cur.seq = g_seq++;
  uint8_t buf[WG_STATE_LEN];
  wgStateEncode(&cur, buf);
  countSend(im920SendEx(buf, sizeof(buf)));   // NG は再送せず次の周期に任せる
  lastSent = cur;
  haveLast = true;
  lastSendMs = millis();
}

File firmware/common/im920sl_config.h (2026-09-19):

// im920sl_config.h
// XIAO RP2040 から IM920sL を設定・制御するヘルパー（Arduino-Pico 用）
// 根拠: IM920sL 取扱説明書 Rev.1.5 (2025.8.22)、IM920sL-ADP 製品資料 Rev.1.0
//
// 機能
//  im920AutoConfig() : 起動時に設定を読み出し、目標値と違う項目だけ ENWR で書き込む
//                      （Flash 書換えは全項目合計 10 万回まで。一致していれば書かない）
//  im920Bridge()     : USB CDC(Serial) <-> IM920sL(Serial1) の透過ブリッジ（IM920-USB2 の代わり）
//  im920Pair()       : STGN によるグループ番号登録（ペアリング）
//  im920Send()       : BUSY を確認して TXDA 送信
//  im920ParseRx()    : 受信行 "aa,bbbb,dd:xx,xx,..." を解析
//
// 配線（回路図どおり / 変換アダプタ IM920sL-ADP の J1/J2）
//  GPIO0 (D6/TX) -> J2-3 RxD   (IM920sL pin6)
//  GPIO1 (D7/RX) <- J1-4 TxD   (pin7)
//  GPIO28 (D2)   <- J1-1 BUSY  (pin1)  L の間だけコマンド受付
//  GPIO29 (D3)   -> J1-10 RESET(pin19) L でリセット、内部 10kΩ プルアップ
//  GPIO2 (D8)    <- SW1（押下で GND、内部プルアップ）
//  J1-9 VCC=3.3V / J2-9 GND / J1-8 STATUS -> LED（任意）
//
// 役割
//  受信機（PC 側）= 親機 ノード 0001（グループ番号に自分の固有 ID が自動設定される）
//  送信機（パッド側）= 子機 ノード 0002（STGN で親機のグループ番号を受け取る）
#pragma once
#include <Arduino.h>

#define IM_SERIAL      Serial1
#define IM_BAUD        19200        // モジュールの初期値（SBRT 4）
// 目標ボーレート。12 バイト送信の UART 時間が 19200bps では約 16ms かかり、
// 電波の送信時間 5.5ms の 3 倍を食っている。115200bps なら約 2.7ms。
// SBRT は取扱説明書に「Flash メモリに記憶します」の記載が無く揮発性とみられるため、
// 毎起動で設定しても Flash 書換え回数（全項目合計 10 万回）を消費しない。
#define IM_BAUD_TARGET 115200       // SBRT 7
#define IM_SBRT_TARGET "7"
#define PIN_IM_BUSY    28
#define PIN_IM_RESET   29
#define PIN_SW_CFG     2

// AutoConfig が目標にするチャンネル（wg_channel.h から書き換えられる）
inline char *im920ChannelBuf() { static char b[4] = "31"; return b; }

// ペアリング済みか（AutoConfig で判定）
inline bool &im920PairedRef() { static bool v = true; return v; }

struct ImParam {
  const char *readCmd;
  const char *setCmd;
  const char *value;    // 読出し応答と同じ書式
};

// 並び順に意味あり: STNN(0001 は ENWR 必須) → STRT（変更するとチャネルが既定値に戻る）→ STCH
static const ImParam IM_PARAMS[] = {
#ifdef IM_ROLE_TX
  {"RDNN", "STNN", "0002"},   // 子機
#else
  {"RDNN", "STNN", "0001"},   // 親機
#endif
  {"RDRT", "STRT", "1"},      // 1=高速モード(100kbps) 2=中距離 3=長距離
  {"RDCH", "STCH", "31"},     // 31〜45 = 4s モード（1時間あたり送信時間の総和制限なし）
                              // 01〜29 = 360s モード（1時間 360 秒まで。高頻度送信だと超過して NG）
  {"RDPO", "STPO", "2"},      // 2=10mW
  {"RDTR", "STTR", "00"},     // キャリアセンス NG 時の自動リトライ回数（遅延を避けるため 0）
};

// ---- 低レベル ----
inline void im920Begin() {
  pinMode(PIN_IM_BUSY, INPUT);
  pinMode(PIN_IM_RESET, INPUT);          // 解放（モジュール内部プルアップで H）
  pinMode(PIN_SW_CFG, INPUT_PULLUP);
  IM_SERIAL.setTX(0);
  IM_SERIAL.setRX(1);
  IM_SERIAL.setFIFOSize(256);
  IM_SERIAL.begin(IM_BAUD);
}

// 指定ボーレートで開き直す
inline void im920Reopen(uint32_t baud) {
  IM_SERIAL.end();
  IM_SERIAL.setTX(0);
  IM_SERIAL.setRX(1);
  IM_SERIAL.setFIFOSize(256);
  IM_SERIAL.begin(baud);
  delay(20);
}

inline void im920Flush() { while (IM_SERIAL.available()) IM_SERIAL.read(); }

// ブロッキング中でも LED の点滅などを続けるためのフック
typedef void (*Im920TickFn)();
inline Im920TickFn &im920TickRef() { static Im920TickFn fn = nullptr; return fn; }
inline void im920SetTick(Im920TickFn fn) { im920TickRef() = fn; }
inline void im920Tick() { Im920TickFn f = im920TickRef(); if (f) f(); }

// 受信データ行（"aa,bbbb,dd:..."）を 1 本だけ退避しておく。
// 送信処理が応答を待っている間に届いた受信行を捨ててしまわないようにする。
inline char *im920StashBuf() { static char b[128]; return b; }
inline bool &im920StashHas() { static bool v = false; return v; }
inline uint32_t &im920StashPuts() { static uint32_t n = 0; return n; }
inline uint32_t &im920RawLines() { static uint32_t n = 0; return n; }

inline void im920StashPut(const String &line) {
  if (line.indexOf(':') < 0) return;
  im920StashPuts()++;              // 受信データ行だけ
  strncpy(im920StashBuf(), line.c_str(), 127);
  im920StashBuf()[127] = '\0';
  im920StashHas() = true;
}
inline bool im920StashTake(char *out, size_t cap) {
  if (!im920StashHas()) return false;
  strncpy(out, im920StashBuf(), cap - 1);
  out[cap - 1] = '\0';
  im920StashHas() = false;
  return true;
}

// 1 行読み（CR/LF 除去）。タイムアウト時は空文字
// 受信データ行は応答ではないので、退避したうえで読み飛ばす
inline String im920ReadLine(uint32_t timeoutMs) {
  String line;
  uint32_t t0 = millis();
  while (millis() - t0 < timeoutMs) {
    while (IM_SERIAL.available()) {
      char c = IM_SERIAL.read();
      if (c == '\n') {
        line.trim();
        if (line.length()) {
          im920RawLines()++;
          if (line.indexOf(':') >= 0) { im920StashPut(line); line = ""; continue; }
          return line;
        }
        continue;
      }
      if (c != '\r') line += c;
    }
    im920Tick();
    yield();
  }
  line.trim();
  return line;
}

// BUSY=L（受付可）になるまで待つ
inline bool im920WaitReady(uint32_t timeoutMs = 200) {
  uint32_t t0 = millis();
  while (digitalRead(PIN_IM_BUSY) == HIGH) {
    if (millis() - t0 > timeoutMs) return false;
    im920Tick();
    yield();
  }
  return true;
}
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

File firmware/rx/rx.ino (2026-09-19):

// rx.ino — 受信機（PC 側）
//   IM920sL で受けたパケットを、USB HID ゲームパッド（＋設定用 CDC）として PC に渡す。
//
//   HID ディスクリプタは、送信機から届く Info パケット（元パッドの軸の種類・ボタン数）
//   をもとに起動時に組み立てる。構成が変わったときは EEPROM に保存して自動で再起動する。
//   こうすると /dev/input/js0 の軸番号・ボタン番号が元のパッドと一致する。
//
//   ビルド: Seeed XIAO RP2040 / USB Stack = Adafruit TinyUSB
//   fqbn: rp2040:rp2040:seeed_xiao_rp2040:usbstack=tinyusb
#include "Adafruit_TinyUSB.h"
#include <EEPROM.h>
#include <pico/unique_id.h>

#include "packet.h"
#include "im920sl_config.h"
#include "hid_desc_builder.h"
#include "status_led.h"
#include "boot_button.h"
#include "im920_diag.h"

// フェイルセーフの閾値は送信間隔に追従させる。
// 送信機はパッド操作中は 30ms、静止中は 60ms キープアライブ（NG の遅延を含む実測で
// 約 105ms）で送るため、固定 300ms だと静止中に 2 連続欠落（約 315ms）で誤発動し、
// 76 分で 90 回フェイルセーフに入っていた（2026-09-19 実測）。
// 受信間隔の 5 倍を閾値にすれば、保護が要る「操作中」は 300ms のまま速く、
// 静止中だけ緩む。真の通信断では間隔が伸びないので必ず上限内で発動する。
static const uint32_t FAILSAFE_MIN_MS = 300;   // 操作中（間隔 30ms）はこの値になる
static const uint32_t FAILSAFE_MAX_MS = 600;   // これ以上は待たない
static const uint32_t FAILSAFE_MULT   = 5;     // 受信間隔の何倍で途絶とみなすか
static uint32_t g_avgIntervalMs = 60;          // 受信間隔の移動平均
static uint32_t g_failsafeMs    = FAILSAFE_MIN_MS;
static const uint32_t HID_PERIOD_MS = 10;   // 変化がなくても送る HID 周期
// 半二重なので、受信機がハートビートを送っている間はパッドのパケットを受け取れない。
// 短い周期にすると前方向のパケット落ちが増えるため、既定は 2 秒にしてある。
static uint32_t g_hbPeriodMs = 2000;

// ---- EEPROM に持つパッド構成 ----
#define WG_PROFILE_ADDR  0
#define WG_PROFILE_MAGIC 0x57475031UL       // 'WGP1'
struct WgProfile {
  uint32_t magic;
  uint8_t  axisMask;
  uint8_t  buttonCount;
  uint8_t  caps;
  uint8_t  pad;
  uint16_t vid, pid;
};

static WgProfile    g_prof;
static WgHidLayout  g_layout;
static uint8_t      g_desc[WG_HID_DESC_MAX];
static uint16_t     g_descLen = 0;

Adafruit_USBD_HID usb_hid;
static WgStatusLed g_led;
static WgBootButton g_btn;
static Im920LineReader g_reader;

// ---- 受信状態 ----
static WgState  g_state;
static uint32_t g_lastRxMs = 0;     // 何かを受信した時刻（統計・表示用）
// フェイルセーフは「操作量を含む State パケット」だけで判断する。
// 2 秒周期の Info パケットでこれを更新してしまうと、State が途絶していても
// Info が 1 つ届くたびに 300ms だけフェイルセーフが解除され、
// **途絶直前の古い操作量（例: スティック全開）が再出力される**。
static uint32_t g_lastStateMs = 0;
static bool     g_failsafe = true;
static uint32_t g_lostAtMs = 0;
static int8_t   g_rssi = 0;
static uint32_t g_pktCount = 0, g_badCount = 0, g_dropCount = 0, g_lostCount = 0;
// 「電波で消えた」のか「受信機が取りこぼした」のかを切り分けるための計測
static uint32_t g_lineCount = 0;      // 行リーダが組み立てた行数
static uint32_t g_parseFail = 0;      // 受信行として解釈できなかった行
static uint32_t g_otherNode = 0;      // 送信機以外のノードからの行
static uint32_t g_uartOver  = 0;      // Serial1 の FIFO 溢れ（＝取りこぼし）
static uint32_t g_maxLoopMs = 0;      // loop() の最大間隔。22ms 超で FIFO が溢れうる
static uint32_t g_gapHist[7] = {0};   // seq の飛びの分布。均一なロスか瞬断かを見る
static uint32_t g_maxGap = 0;         // 最大の連続欠落数
static uint32_t g_slowLoops = 0;      // 10ms を超えた loop() の回数
static uint8_t  g_lastSeq = 0;
static bool     g_haveSeq = false;
static WgInfo   g_lastInfo;
static bool     g_haveInfo = false;
static uint8_t  g_infoStreak = 0;
static uint32_t g_hidSent = 0, g_hidSkip = 0, g_wakeReq = 0;
static uint32_t g_hbLastMs = 0, g_hbSent = 0, g_hbBusy = 0;
// 応答待ちなし送信なので、OK/NG 行はメインループの行読みが拾う。ここで数える
static uint32_t g_respOk = 0, g_respNg = 0;
// 送信タイミング: 受信直後に送るのが最も通る。
// 受信機は常時パケットを受けており、その最中はキャリアセンスが通らないため、
// 単純な周期送信では TXDA が 8 割以上 NG になる（実測 OK=1/NG=6）。
// 送信機がパケットを送り終えた直後はチャネルが空き、送信機も受信待ちなので確実。
static bool     g_hbDue = false;

// ---- チャンネル追従 ----
// 送信機の通知で移動し、一定時間 State が来なければ待ち合わせ ch31 へ戻る
#define WG_CH_HOME 31
static const uint32_t CH_REVERT_MS = 12000;
static uint8_t  g_curCh = WG_CH_HOME;
static uint8_t  g_hbSeq = 0;
static bool     g_hbEnable = true;
static uint8_t  g_hidLast[WG_HID_REPORT_MAX];
static uint8_t  g_hidLastLen = 0;

static const uint32_t WDT_MS = 4000;

static void ledTick() {
  g_led.task();
  rp2040.wdt_reset();
}

// =====================================================================
// プロファイル
// =====================================================================
static void profileDefault(WgProfile *p) {
  p->magic = WG_PROFILE_MAGIC;
  p->axisMask = 0x3F;                     // X, Y, Z, Rx, Ry, Rz
  p->buttonCount = WG_BUTTON_MAX;
  p->caps = WG_CAP_HAT;
  p->pad = 0;
  p->vid = p->pid = 0;
}

static void profileLoad() {
  EEPROM.get(WG_PROFILE_ADDR, g_prof);
  if (g_prof.magic != WG_PROFILE_MAGIC || (g_prof.axisMask & ~0x3F) ||
      g_prof.buttonCount > WG_BUTTON_MAX ||
      (g_prof.axisMask == 0 && g_prof.buttonCount == 0)) {
    profileDefault(&g_prof);
  }
}

static void profileSave() {
  g_prof.magic = WG_PROFILE_MAGIC;
  EEPROM.put(WG_PROFILE_ADDR, g_prof);
  EEPROM.commit();
}
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

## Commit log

2026-09-19 USB ゲームパッドを 920MHz で無線化するファームウェア一式
    既存の USB ゲームパッドを、Bluetooth より長距離に届く 920MHz 帯（IM920sL）で
    無線化する。ロボットの遠隔操縦用。
    - 送信機(XIAO RP2040): コア1 で PIO-USB ホスト、コア0 で IM920sL 送信と CDC コンソール
    - 受信機(XIAO RP2040): 無線受信と USB HID ゲームパッド + CDC コンソール
    - 送信機が HID レポートディスクリプタを解析し、軸構成を Info パケットで送る。
    受信機はそれを EEPROM に保存して HID ディスクリプタを実行時に組み立てるため、
    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
    [gamepad_wireless_BOM.xlsx]
2026-09-19 MIT ライセンスを追加し、README をリポジトリのトップとして整理
    - LICENSE（MIT）を追加
    - README の冒頭を、引き継ぎ資料ではなくリポジトリの導入として書き直した
    - 何ができるか、特徴（軸番号の一致・フェイルセーフ・チャンネル自動選定・暗号化）
    - 必要な部品の一覧
    - arduino-cli の準備から書込み・ペアリング・確認までの最短手順
    - 実装と実機検証の詳細は以降にそのまま残してある
2026-09-19 回路図を Rev.3 に更新し、BOM を実装に合わせて整理
    現在の実装に合わせて回路から次を削除した。
    - SW1（SW_CFG）: 設定/ペアリングは XIAO の BOOTSEL で行うため未実装
    - STATUS LED（LED1 / R3）: 状態表示は XIAO オンボードのカラー LED を使うため未実装
    あわせて実配線に合わせた修正:
    - USB の D+/D− を GPIO26/GPIO27 に（実機で機器のプルアップ位置から確認）
    - CPU クロックの記述を 120MHz から 240MHz に
    回路図は Chromium 印刷の PDF/PNG しか無く編集できなかったため、
    SVG をソースとして作り直した（docs/schematic/）。Rev.2 の PDF/PNG は削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
    [gamepad_wireless_BOM.xlsx]
2026-09-19 HANDOFF.md を Rev.3 の実配線に合わせて修正
    実装前に書かれた資料なので、現在の仕様は README が正である旨を冒頭に追記。
    D+/D- の割り当て（GPIO26=D+）、PIO-USB の設定例、CPU クロック、
    SW1 廃止を反映した。
2026-09-19 回路図の USB ネット割り当てを実配線に修正
    表示が崩れていた SVG を作り直していただいたが、USB の D+/D- が Rev.2 の
    割り当て（GPIO26=D-, GPIO27=D+）のままだったため、実機で確認した現在の
    配線（GPIO26=D+, GPIO27=D-）に合わせた。直列抵抗の R1/R2 も D-/D+ に
    対応させ、設計メモの pin_dp と CPU クロックも更新した。
2026-09-19 KiCad のフットプリントと寸法確認シートを追加
    基板設計に向けた準備。KiCad 6 の pcbnew Python API で生成・描画まで
    自動化してある（KiCad 6 には kicad-cli が無いため）。
    - IM920sL-ADP のフットプリント（製品資料 Rev.1.0 の外形寸法図から作成）
    - XIAO RP2040 のフットプリント（列間隔は未確認のため要実測）
    - 1:1 印刷して実物と突き合わせるための確認シート（50mm 基準線つき）
    README に免責事項を追加した。個人の原理試作であり動作・性能・安全性を
    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
    [checksheet.kicad_pcb]
2026-09-19 基板の部品配置を作成（DRC クリーン）
    XIAO のピン間隔を実測値 0.6in（15.24mm）に確定。ADP の寸法も実物で確認済み。
    配置:
    - U2(ADP) を左端に寄せ、左側をアンテナ用に空ける。180 度回して信号の多い
    J1 側（BUSY/RESET/TxD/VCC）を XIAO に向けた
    - U1(XIAO) を中央右、C2/C3 を両者の間、R1/R2 と J1(USB-A DIP 基板用 4 ピン)
    と C1 を右側に配置
    - 基板 90x50mm
    pcbnew の DRC で配置の重なり・クリアランス違反が 0 であることを確認
    （未配線 18 件は配線前のため）。配線はこれから。
    [gamepad_over_920MHz.kicad_pcb]
2026-09-19 基板を配線し、GND ベタと四隅の固定穴を追加（DRC 0 violations）
    - 全 11 ネットを配線。D+ は表面、D− は裏面（XIAO 側と J1 側で
    D+/D− の上下が逆転しており 1 層では必ず交差するため）
    - 両面 GND ベタ。左上 22x20mm はアンテナ用に銅を抜いた
    - 四隅に φ3.2（M3）の固定穴を追加。外形を 100x62mm に拡大
    - J1 のシェル固定パッドを GND に接続
    - 確認用に表面・裏面の PDF を個別出力
    [gamepad_over_920MHz.kicad_pcb]
2026-09-19 発注用のガーバー・ドリルデータを出力する make_gerber.py を追加
    - board/gerber/ に銅箔・シルク・レジスト・メタルマスク・外形と
    PTH/NPTH のドリルを出力し、ZIP にまとめる
    - 拡張子は Protel 形式（.GTL など）。業者を選ばない
    - 固定穴は NPTH として分離
    - README に発注時の指定値を追記
    [gamepad_over_920MHz-B_Cu.gbl, gamepad_over_920MHz-B_Mask.gbs, gamepad_over_920MHz-B_Paste.gbp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]
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2026-09-19 docs/HANDOFF.md を削除し、必要な内容を README に取り込んだ
    実装前のコーディング引き継ぎ資料であり、実装が済んだ現状では
    記述が古く（§4 の API 一覧、§5 のパケット案）誤解を招くため削除する。
    残す価値のあった内容は README に移した:
    - IM920sL の設定値（STNN/STRT/STCH/STPO/STTR）の表
    - 4s モードの強制休止の挙動（HANDOFF の記述の訂正として書いていたものを
    独立した説明に書き直した）
    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
2026-09-19 BOM をコネクタ類の内訳と基板設計の実態に合わせて修正
    抜けていた項目を追加:
    - ピンヘッダ 1x10 (ADP 側) x4
    - ピンソケット 1x10 (基板側・ADP 受け) x4
    - ピンソケット 1x7 (基板側・XIAO 受け) x4
    - ピンヘッダ 1x7 (XIAO 側) は付属品のため数量 0 で参考掲載
    - プリント基板、M3 ネジ・スペーサー
    基板設計に合わせた修正:
    - USB-A は DIP 化基板をやめて基板直付け (DS1095-WNR0 相当) に
    - ユニバーサル基板 x2 をプリント基板に置き換え
    集計式の誤りを修正:
    - H22 が =F23*G23、H23 が =F25*G25、H24 が =F26*G26 と
    1〜2 行ずれており、ADP 2 個分 2,8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
    [gamepad_wireless_BOM.xlsx]
2026-09-19 送信間隔を 90ms に引き上げ、4s モードの規定を README に正しく記載
    取扱説明書 Rev.1.5 表1・§7-3 を再確認した結果:
    - ch31〜45（4s モード）に 1 時間あたりの総和制限は無い（360s モードのみ）
    - 代わりに「送信休止 52ms 以上」があり、占有約 12ms を足すと
    計算上の最小間隔は 64ms。従来の 30ms/60ms はこれを満たしていなかった
    実装:
    - 使われていなかった TX_MIN_INTERVAL を g_txMinInterval の初期値として接続
    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
2026-09-19 送信間隔を 30/60ms に戻し、受信機に欠落の切り分け計測を追加
    90ms への引き上げは実測で逆効果だったため差し戻す（NG は単発でしか
    起きず次の周期で回復するので、間隔を詰めたほうが実効レートが高い）。
    受信機に追加した計測:
    - UART の FIFO 溢れ（Serial1.overflow）
    - 行リーダが組み立てた行数・解釈不能行・他ノード行
    - loop() の最大間隔と 10ms 超の回数
    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
2026-09-19 動作中に突然リンク断になる問題を修正（ハートビートのタイムアウト）
    原因: 送信機のモジュールは半二重で、送信中は受信できない。実測では
    送信間隔 60ms で 6.6%、30ms（操作中）で 29.5% のハートビートを取りこぼす。
    ハートビートは 2 秒周期なので、HB_TIMEOUT_MS=5000 では 2 回連続の欠落
    （操作中は 8.7%/2秒）でリンク断と誤判定し、平均 20〜30 秒に 1 回
    赤点滅していた。さらに CH_REVERT_MS=12000 も同じ判定を使うため、
    6 回連続の欠落で ch31 へ戻って再走査し、受信機を取り残して
    本当の通信断を作っていた。
    修正: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
    [tx.ino]
2026-09-19 送信後に消える約 15% のパケットを「未解明の既知事象」として記録
    送信出力を 10mW から 1mW に落として比較したが、RSSI が −12dBm から
    −21dBm に下がってもロス率は 21.1% → 22.9% と変わらなかった。
    至近距離による受信機の飽和という仮説は否定される。
    これまでに否定できた原因（干渉・受信機の取りこぼし・処理落ち・
    パケット破損・ハートビートとの衝突・送信間隔・受信機の飽和）を
    README に表でまとめ、実害が無いことの根拠（欠落は必ず単発で
    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
2026-09-19 reports がパッド無操作時に増えないのは正常、と README に明記
    多くのゲームパッドは状態変化時のみ HID レポートを返すため、
    触っていなければ reports=1 のままになる。実機で操作したところ
    2512 まで増えることを確認した。PIO-USB の生死は usb コマンドの
    epErr / epStall / コア1 の loop 回数で判断する。
    あわせて、確認リストの NG 率を再測定値に修正した。
    初期の「30ms で 0%」は短時間測定の値で、長時間動かすと
    30ms で約 22%、60ms で約 8% になる。
2026-09-19 送信機に再起動しても消えないブラックボックス記録を追加
    赤点滅や自動再起動が起きるとカウンタがリセットされ、原因を追えなかった。
    __uninitialized_ram はソフトリセットで保持されるので、そこに記録する
    （電源を抜くと magic が壊れてクリアされるため、自動再起動と
    手動の電源断を区別できる）。
    記録する内容:
    - ソフト再起動の回数と、直近の自動再起動の理由・そのときの稼働時間と主要カウンタ
    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
2026-09-19 core1 停止からの復帰を 21 秒から数秒に短縮
    ブラックボックスで原因を特定した。動作中の突然の再起動は
    core1（PIO-USB）の停止によるもので、無線は無関係だった
    （停止時点でハートビートは 223ms 前に受信、リンクは健全）。
    赤点滅の原因もパッド切断であり、その 9 秒後に監視機構が
    再起動をかけている。loop1() は g_hostTicks++ が先頭なので、
    止まっているのは USBHost.task() の中。
    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
2026-09-19 NeoPixel を切り離せる neo on|off コマンドを追加（core1 停止の切り分け用）
    Adafruit_NeoPixel::show() は RP2040 でも実行中ずっと noInterrupts() で
    割り込みを止めるが、arduino-pico の noInterrupts() は get_core_num() で
    コア別に管理されるため、core0 で止めても core1 の割り込みは止まらない。
    show() は core0、PIO-USB は core1 なので、割り込み阻害が直接の原因という
    線は薄い。
    ただし NeoPixel と PIO-USB は PIO ハードウェアを共有しており
    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
2026-09-19 受信機のフェイルセーフ閾値を送信間隔に追従させる
    固定 300ms では、パッド静止時（実効送信間隔 約105ms）に 2 連続欠落
    （約315ms）で誤発動し、76 分で 90 回フェイルセーフに入っていた。
    赤点滅 8 回のうち 6 回がこれに由来していた。
    受信間隔の移動平均 × 5 を閾値とし、300〜600ms に制限する。
    欠落分は seq の飛びで割り戻すので、ロスがあっても閾値は伸びない。
    - パッド操作中（間隔 30ms）… 閾値 300ms（従来どおり速く保護）
    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
2026-09-19 core1 が固まった瞬間の PIO-USB レジスタをブラックボックスに記録
    NeoPixel 干渉の仮説は棄却された（neo off でも 30 分で core1 停止が発生）。
    Pico PIO USB 0.7.2 と Adafruit TinyUSB 3.7.7 はいずれも最新版で、
    ライブラリ更新による解決も望めない。
    根本原因を追うには、固まった瞬間の状態が要る。core1 は止まっていても
    core0 からは PIO-USB のレジスタを読めるので、停止を検出した時点で
    以下を記録する:
    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
2026-09-19 ネイティブ USB ホストの動作確認用スケッチを追加
    XIAO RP2040 の USB-C に OTG 変換でパッドを繋ぎ、PIO-USB を使わずに
    列挙・レポート受信ができるかを確かめる最小構成。これが動けば
    core1（PIO-USB）の停止は構造的に解消する。
    - arduino-pico は seeed_xiao_rp2040 でも usbstack=tinyusb_host に対応
    - USBHost.begin(0) でネイティブコントローラを使う。core1 は不要
    - ホストモードでは USB の CDC が使えないため、判定は LED のみで行う
    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
2026-09-19 ネイティブホストのテストで停止箇所を色分けできるようにした
    最初の版は「水色になるか」しか分からず、水色にならなかったときに
    どこで止まったのか切り分けられなかった。
    tuh_mount_cb（HID に限らず USB 機器を検出）を足し、
    tuh_hid_receive_report の戻り値も見て、状態を分けて表示する:
    白の点滅 USBHost.begin() から戻っていない（初期化で停止）
    赤の点滅 USB 機器を何も検出していない（給電を疑う）
    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
